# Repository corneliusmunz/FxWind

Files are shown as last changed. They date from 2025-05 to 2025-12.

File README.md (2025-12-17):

# FxWind

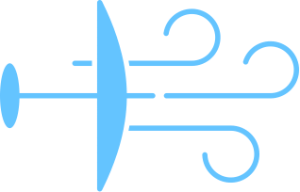
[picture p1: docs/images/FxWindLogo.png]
FxWind Logo


FxWind is a wind measurement tool for FAI Aeromodeling contests. In the FAI rules for 
different contest classes like F3B, F3J, F3K, etc. there are defined rules under which wind
conditions a contest can take place and under which conditions a contest has to be 
interrupted. FxWind will help you to comply with these competition rules.

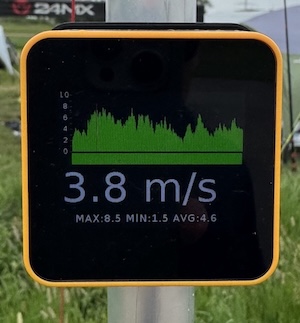
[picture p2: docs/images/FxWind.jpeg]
FxWind Display


All HW and SW Parts are published as open source and could be used to build your own measurement
tool. 

Feel free to open an issue or participate in the development by opening a pull request.

# Features

- [x] Battery powered. Last one complete competition day of at least 12 hours
- [x] Recharchable by USB-C in 2-3 hours
- [x] Additional Backup Power by USB-C
- [x] Magnetic connection between sensor and display, no wiring
- [x] 3D Printed parts for Microcontroller and accessories
- [x] Simple Alloy tube as base rig
- [x] Waterproof
- [x] Logging of Windspeed and Datetime on SD-Card for auditabilty, traceabiliy and possible complaints
- [x] 1s Sampling rate 
- [x] Wifi or Accesspoint connection to display the windspeed conditions on a webpage
- [x] Time synchronisation with NTP server and local backup of date and time with a Real Time Clock (RTC) 
- [x] Touch display with current windspeed and the needed ranges
- [x] Visualisation of regions in the time plot where the wind thresholds has exceeded
- [x] Accustic alarm if the condition are met to interrupt a contest

# How to use

You can find the operation manual on the following link
[Operation Manual](docs/OperationManual.md)

# Setup

## Mechanical setup

The windspeed sensor and the controller with display are mounted on a alloy tube which has the specified height of 2m above the ground. The original controller case of the M5Tough device is replaced by a 3D printed part which contains the rechargeable battery, the magnetic connector, the USB-C port and the magnetic Pogo Pin connector for the electric connection to the wind sensor. The controller and USB-C Port is sealed with an O-ring to ensure the waterproof design. The alloy tube is splitted into two parts for better transportability and could be sticked together with a tube connector. 

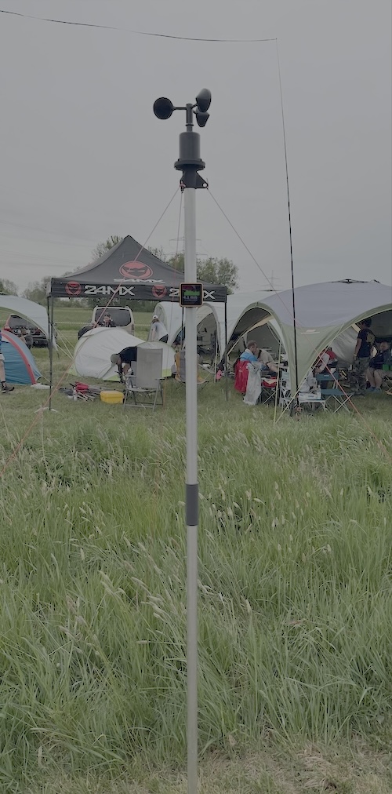
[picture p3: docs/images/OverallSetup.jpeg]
Overall setup

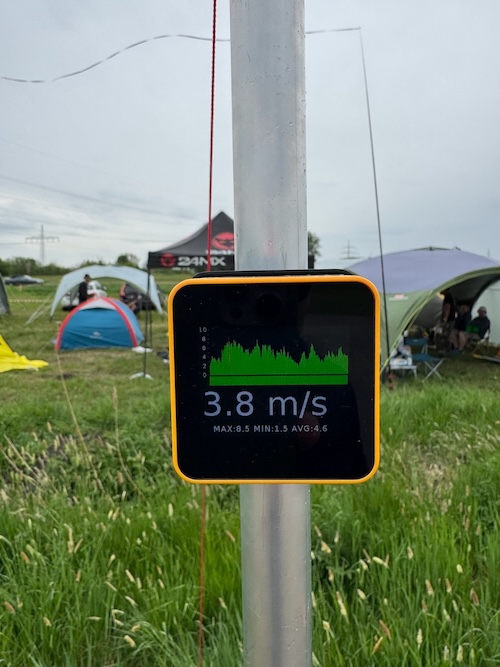
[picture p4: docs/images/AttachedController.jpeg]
Attached controller

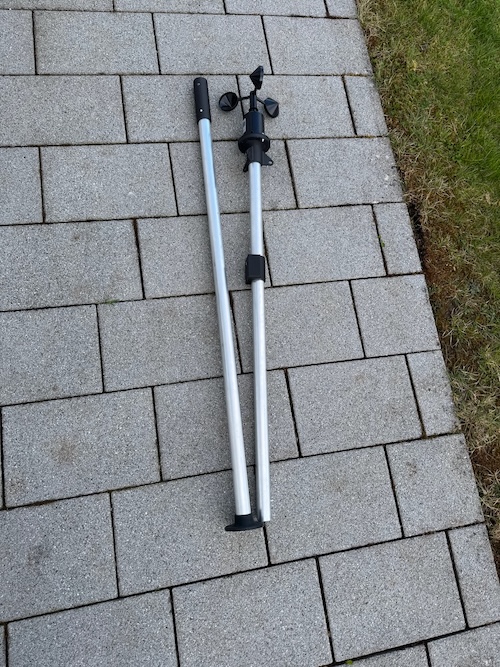
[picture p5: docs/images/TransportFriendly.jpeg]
Transport setup

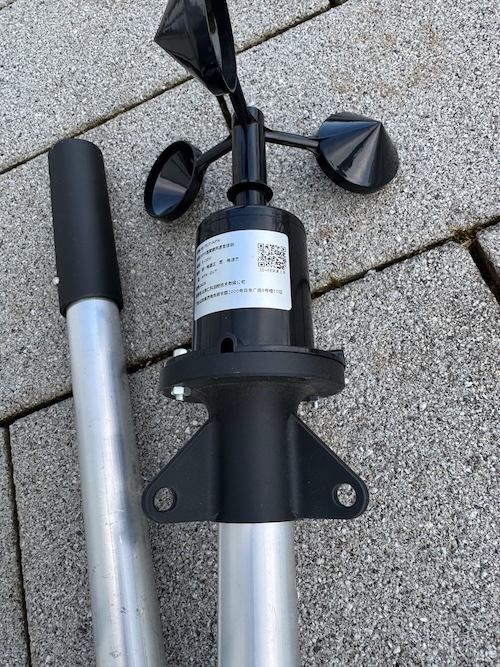
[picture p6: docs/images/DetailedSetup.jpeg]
Detailed setup

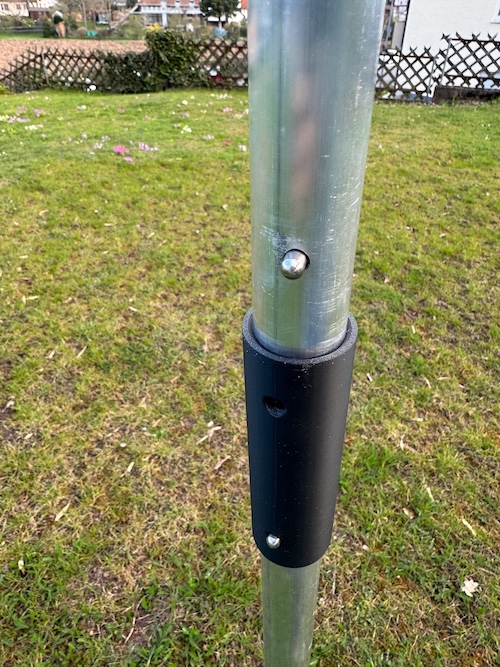
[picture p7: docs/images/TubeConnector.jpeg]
Tube connector


### CAD, STL Files 

## Electronic setup

### Wiring

## BOM

| Part | Quantity | Description | Link |
| --- | --- | --- | --- |
| M5Tough | 1 | Microcontroller with Touchscreen | https://docs.m5stack.com/en/core/tough |
| 1S 2000mAh Lipo | 1 | | https://www.amazon.de/dp/B08TQSC5G9 |
| Magnet | 1 | Magnet for connection between Controller and Base rig | https://www.amazon.de/dp/B0BKWQX36P |
| Windspeed Sensor | 1 | Windspeed sensor with impuls output and connection wiring | https://www.amazon.de/dp/B0C2F5MGKZ |
| Magnetic 3pin Pogo connector | 1 | Connection between Controller case and Base rig | https://www.amazon.de/dp/B0B1771YT4 |
| USB-C Port | 1 | USB-C Port for SW upload and as input for battery charge | https://www.amazon.de/dp/B0CZHDMFLZ |
| Ruthex M3S Brass Threads | 6 | M3 Short Brass inserts for meltin into the 3D Printed parts | https://www.amazon.de/dp/B09ZHSGHXD |
| M3x10 Flathead screw | 4 | Threads for clamp | |
| M3x6 countersunk screw | 2 | Threads for securing the magnet and the metal plate | |
| Alloy tube 30mm diameter | 2m | Base rig, 2x 1m length | |
| Base socket for Alloy tube | 1 | 3D printed part | [Base socket](construction/BottomStand.stl) |
| Windsensor socket | 1 | 3D printed part | [Windsensor socket](construction/TopStand.stl) |
| Controller case | 1 | 3D printed part | [Controller case](construction/FxWind_Case.stl) |
| Base plate for controller case | 1 | 3D printed part | [Base plate](construction/FxWind_ClampCase.stl) |
| Clamp | 1 | 3D printed part | [Clamp](construction/FxWind_Clamp.stl) |
| Tube connector | 1 | 3D printed part | [Tube connector](construction/FxWind_Connector.stl) |

## Assembly

You can find the assembly instructions on the following link
[Assembly Instructions](docs/assembly.md)

## Software

The software is based on the Arduino framework and is build, using the [PlatformIO](https://platformio.org)  develompent environment. You have two options to get the Software on the controller. You can build the Software by your own or you can use the provided binaries in the [Release](https://github.com/corneliusmunz/FxWind/releases) section and use an online flash tool. Both options are described in the next sections.

### Build

You can build the software by your own in opening the project in [PlatformIO](https://platformio.org) and choose the option ```Upload```. After the build process, the binaries will be flashed on the connected device. In a second step, you have to use the option ```Build Filesystem Image```. This step will generate a bin file which contains the html and image files which are needed for the web interface. In a last step, you have to use the option ```Upload Filesystem Image```. This will flash the filesystem image on your controller. 

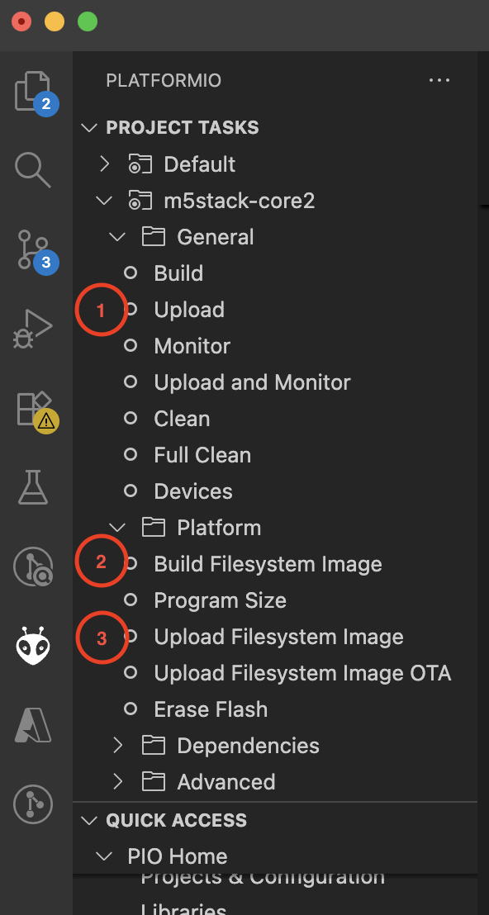
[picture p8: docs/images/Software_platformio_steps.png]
PlatformIO Build steps


### Flash without build

If you want to use the precompiled binaries out of the [Release section](https://github.com/corneliusmunz/FxWind/releases), you can open the following flash tool: https://espressif.github.io/esptool-js/ It is important, that you use the tool in a Chrome based browser. 

After opening the webpage, you have to change the baudrate to the value ```460800``` and press the ```Connect``` Button. 

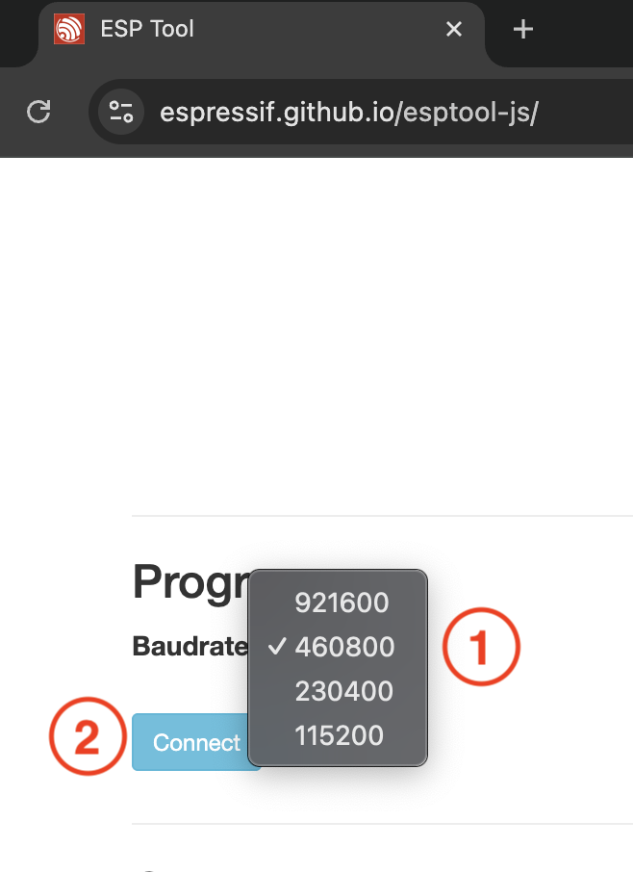
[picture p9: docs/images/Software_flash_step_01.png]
Flash step 1


The next step is to erase the flash on the controller. After doing this, enter the Flash Address ```0x0```and select the ```firmware-merged.bin```file out of the release assets. Then press the ```Program``` button and wait until the flash process is finished. 

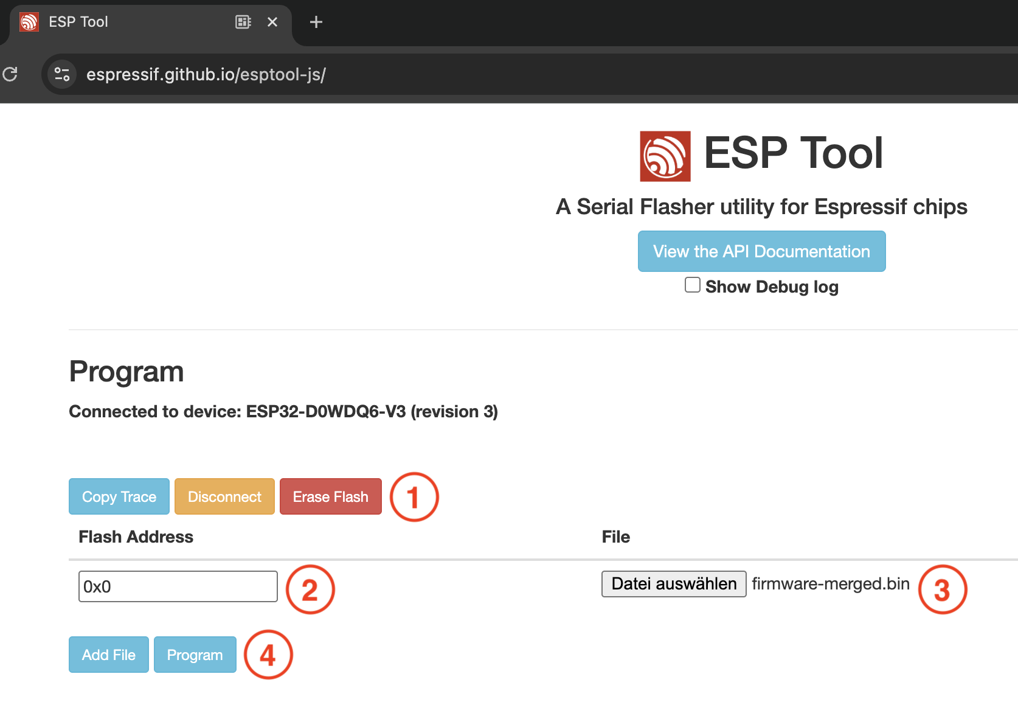
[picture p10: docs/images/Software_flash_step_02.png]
Flash step 2


In the final step, the filesystem has to be flashed on the controller. For this task you have to enter the Flash Address ```0x00c90000``` and select the ```littlefs.bin``` file out of the release assets. Then press the ```Program``` button. Now you are done and the controller is ready to go.

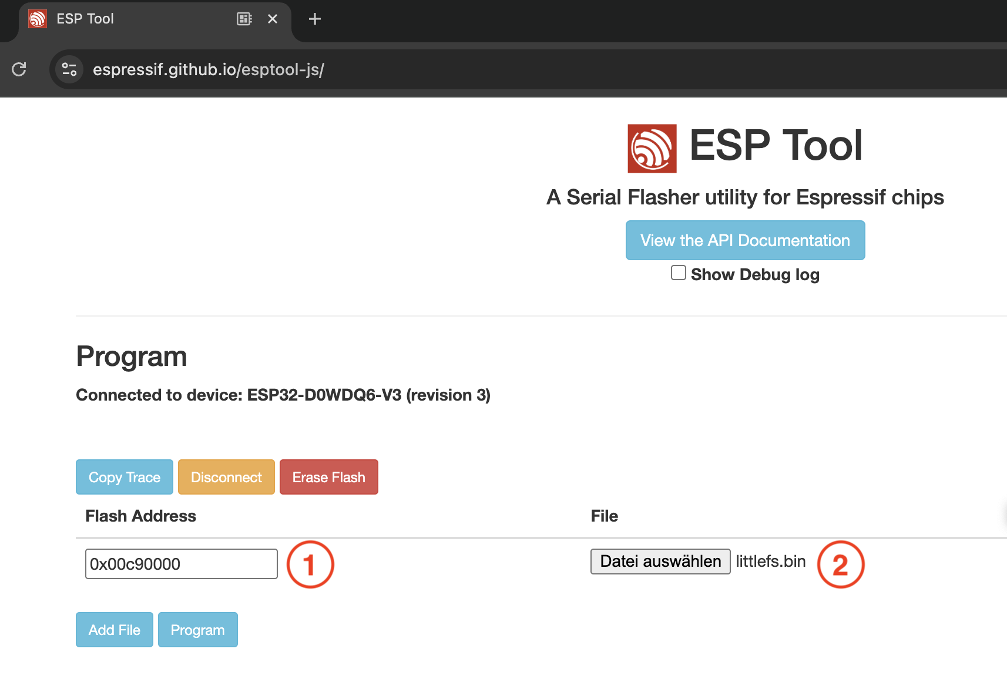
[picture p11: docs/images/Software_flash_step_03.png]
Flash step 3


# Ideas and open issues

- [ ] BLE connection 

# Appendix

## FAI rule links

FAI Sporting code rc modeling soaring 
https://www.fai.org/sites/default/files/sc4_vol_f3_soaring_25.pdf

### Overview of conditions for different FAI competition categories

| Category | Lower Windspeed threshold [m/s] | Upper Windspeed threshold [m/s] | Window duration [s] | Number of windows exceeded |
| --- | --- | --- | --- | --- |
| **Gerneral** | 0 | 12 | 60 | 1 |
| **F3K** | 0 | 8 | 20 | 3 |
| **F3B** | 0 | 12 | 20 | 3 |
| **F3G** | 0 | 12 | 20 | 3 |
| **F3J** | 0 | 12 | 20 | 3 |
| **F3L** | 0 | 8 | 60 | 1 |
| **F3F** | 3 | 25 | 20 | 1 |
| **F1x** | 0 | 9 | 20 | 1 |
| **F2x** | 0 | 9 | 30 | 1 |
| **F3C/F3N**  | 0 | 8 | 20 | 1 |

### Extracts

Extracts of the sporting codes of different FAI competition categories

#### CIAM General rules

> C.17.2 Interruption
> a) The contest should be interrupted or the start delayed by the contest director in the following
> circumstances and in other exceptional circumstances decided by the contest director:
> i) Unless specified otherwise in the rules for a category or a particular class, the wind is
> continuously stronger than **12 m/s** measured **at two (2) metres** above the ground at the starting
> line (flight line), **for at least one minute**

#### Soaring F3B

> F3B.1.11. Weather Conditions / Interruptions
> a) The maximum wind speed for F3B contests is twelve (12) m/sec. The > contest has to be interrupted
> or the start delayed by the contest director if the wind speed exceeds > twelve (12) m/sec measured three (3)
> times for at least twenty (20) seconds in a time interval of five (5) > minutes two (2) metres above the ground
> at the start and landing area.

#### Soaring F3F

> F3F.1.17. Weather Conditions and interruptions
> A round in progress must be interrupted if:-
> The wind speed is below three (3) m/sec or more than twenty-five (25) m/> sec for at least twenty (20)
> a) seconds.
> b) The direction of the wind deviates more than 45º from a line > perpendicular to the main direction of
> the speed course for at least twenty (20) seconds.
> The wind speed and wind direction are measured with the equipment of the > organiser at a representative
> position and height chosen from the experience of the organiser.

#### Soaring F3G

> F3G.1.12. Weather Conditions/Interruptions
> a) The maximum wind speed for F3G contests is twelve (12) m/sec. The > contest has to be interrupted
> or the start delayed by the contest director if the wind speed exceeds > twelve (12) m/sec measured three (3)
> times for at least twenty (20) seconds in a time interval of five (5) > minutes two (2) metres above the ground
> at the start and landing area.

#### Soaring F3J

> F3J.12. WEATHER CONDITIONS AND INTERRUPTIONS
> The maximum wind speed for F3J contests is twelve (12) m/sec two (2) m > above the ground at the centre of
> the launch corridor. The start of the contest must be delayed or the > contest has to be interrupted by the
> contest director if the wind speed exceeds twelve (12) m/sec measured > three (3) times for at least twenty
> (20) sec in a time interval of five (5) minutes at the start and landing > area.

#### Soaring F3K

> F3K.5. WEATHER CONDITIONS / INTERRUPTIONS
> The maximum wind speed for F3K contests is eight (8) m/sec. The start of > the contest must be delayed or
> the contest has to be interrupted by the contest director if the wind > speed exceeds eight (8) m/sec measured
> three (3) times for at least twenty (20) sec in a time interval of five > (5) minutes at two (2) metres above the
> ground at the start and landing field. In the case of rain, the contest > director can interrupt the contest. When
> the rain stops, the contest starts again with the group that was flying, > which receives a re-flight.

#### Soaring F3L

> F3L.6 Interruptions
> a) The Contest Director has the right to interrupt the competition and > relocate the starting line
> when the wind direction deviates too much or becomes a tailwind.
> b) The competition shall be interrupted by the Contest Director if the > wind is continuously
> stronger than eight (8) m/s measured at two (2) metres above the ground > at the starting line (flight
> line), for at least one minute.

#### Helicopter

> INTERRUPTION OF A COMPETITION
> If the wind component perpendicular to the flight line exceeds 8ms/s for > a minimum of 20 seconds
> during a flight, the competition must be interrupted. The flight will be > repeated and the competition
> continued as soon as the wind subsides below the criterion. If the wind > does not subside before the
> round is completed, the entire round will be dropped. The determination > will be made by the organiser
> with concurrence of the FAI Jury.

#### Free flight

> F1.5 INTERRUPTION OF A CONTEST
> F1.5.1 Wind speed
> The interruption of contests is defined in CIAM General Rules C.17.2. > For Free Flight contests the
> contest should be interrupted when the wind measured at 2 metres above > the ground at the starting
> line is stronger than 9 m/s for at least 20 seconds.

#### Control line

> 4.0.1 INTERRUPTION OF THE CONTEST
> Wind stronger than 9 m/s for at least 30 seconds (instead of 12 m/s for > at least one minute in
> CIAM General Rules).

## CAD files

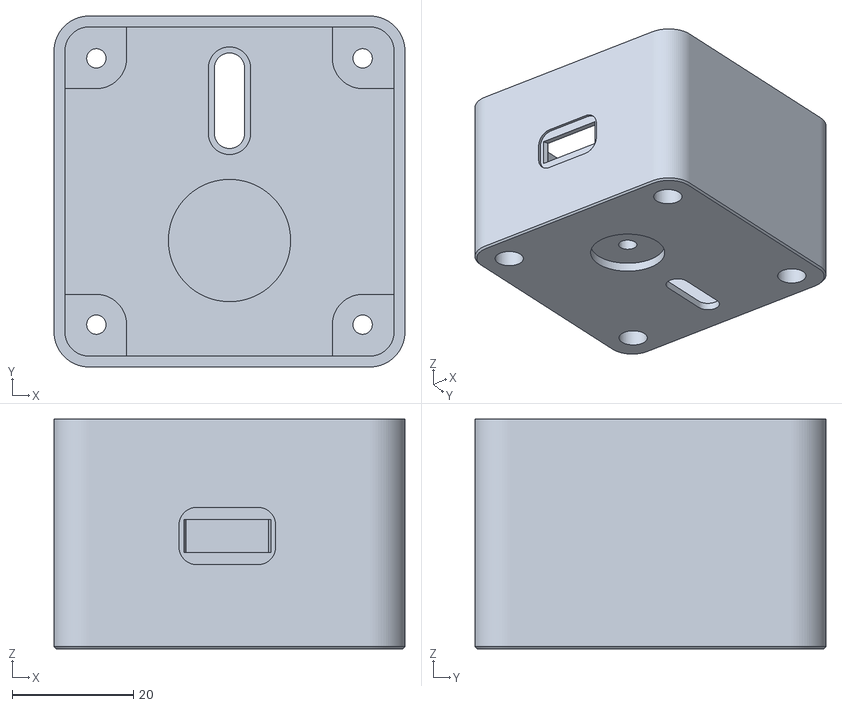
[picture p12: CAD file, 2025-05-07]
construction/FxWind_Case.stl
58.0 x 58.0 x 38.0

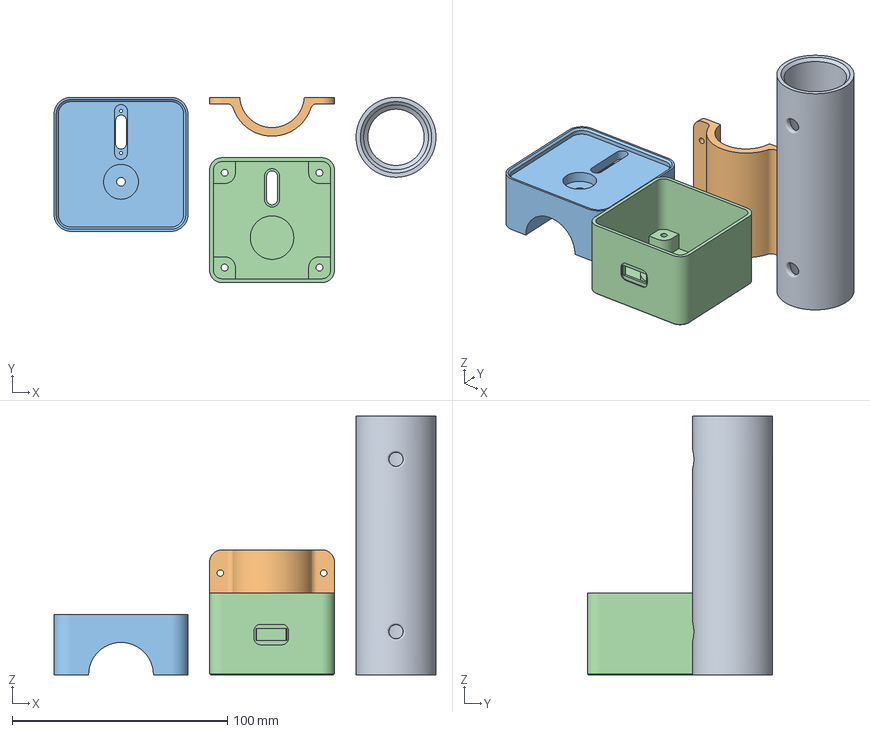
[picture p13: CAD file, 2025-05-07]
construction/FxWind.3mf
177.3 x 86.0 x 120.0 mm
FxWind_Connector.stl
FxWind_Clamp.stl
FxWind_ClampCase.stl
FxWind_Case.stl

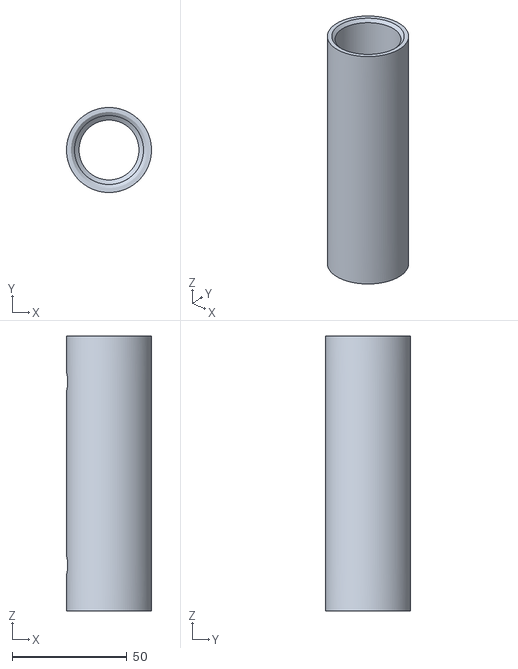
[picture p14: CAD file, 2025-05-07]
construction/FxWind_Connector.stl
37.1 x 37.1 x 120.0

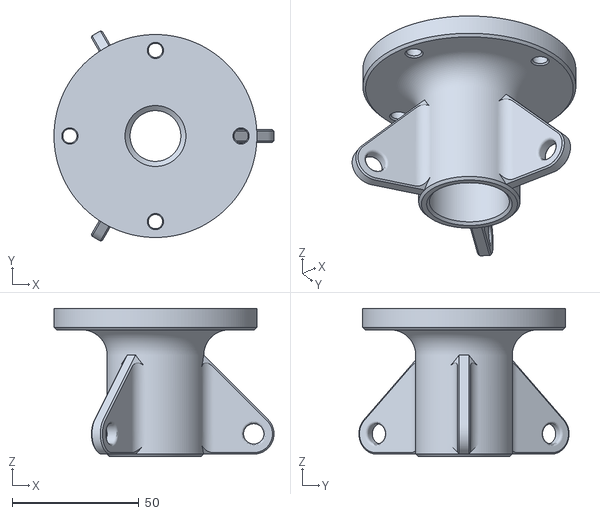
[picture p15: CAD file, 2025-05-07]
construction/TopStand.stl
86.7 x 82.8 x 58.5

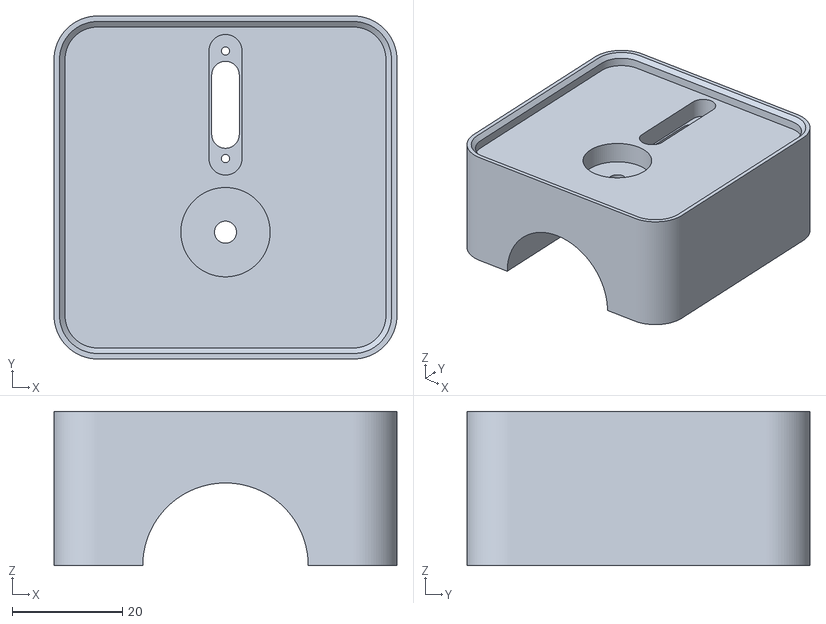
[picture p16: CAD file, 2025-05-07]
construction/FxWind_ClampCase.stl
62.2 x 62.2 x 28.0

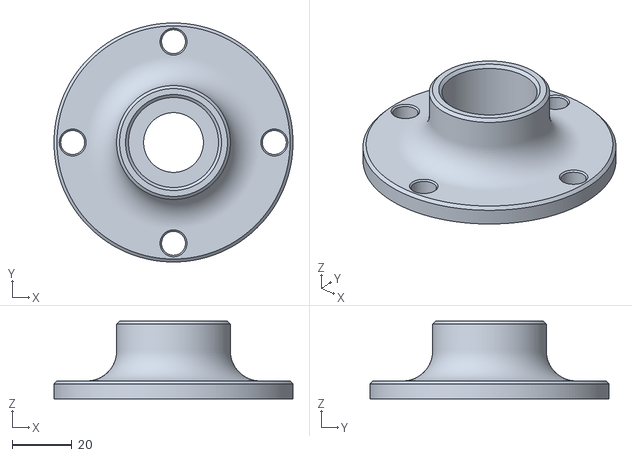
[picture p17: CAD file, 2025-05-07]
construction/BottomStand.stl
80.0 x 80.0 x 26.0

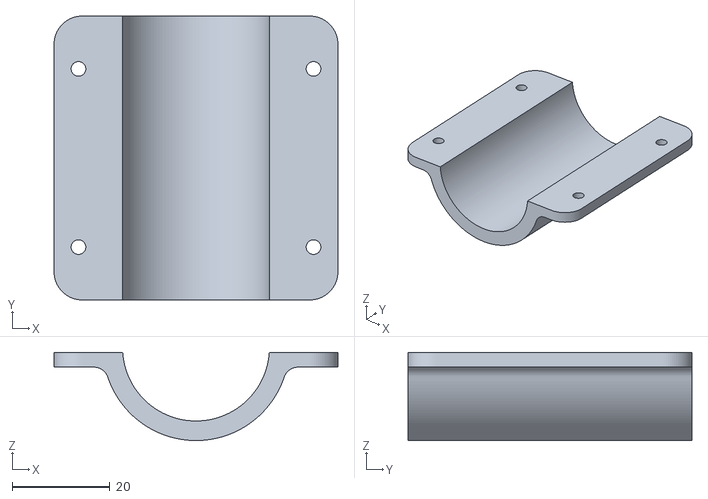
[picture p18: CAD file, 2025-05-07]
construction/FxWind_Clamp.stl
58.0 x 58.0 x 18.0

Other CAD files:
construction/FxWind.f3d

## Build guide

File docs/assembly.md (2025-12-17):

# Assembly

After you have ordered and printed all the materials on the BOM, you can start the assembly of the measurement device. 

## Brass threads

To mount the magnet we have to melt 2 Ruthex M3S Brass Threads into the controller body and the clamp body. Additionally we have to melt 4 Ruthex M3 Brass Threads into the clamp body

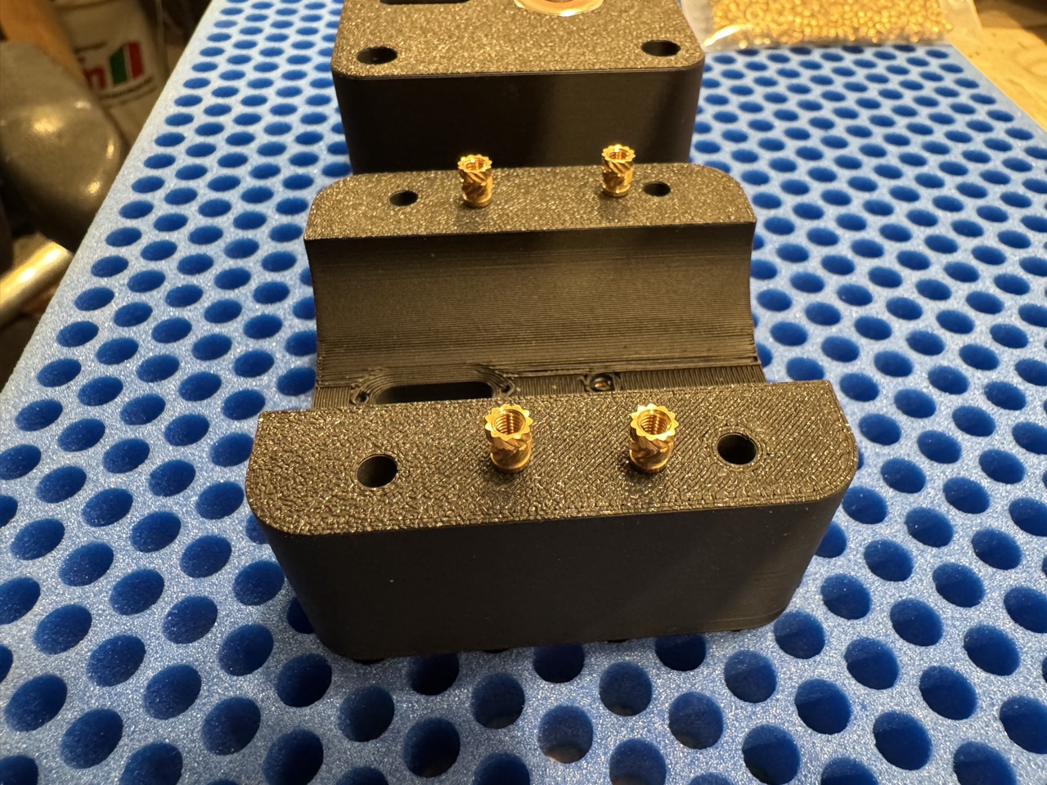
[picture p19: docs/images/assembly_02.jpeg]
Brass threads


## Magnet
The magnet and spacer is mounted with two M3x6 countersunk screws. The magnet is part of the clamp body and the spacer is part of the controller body.

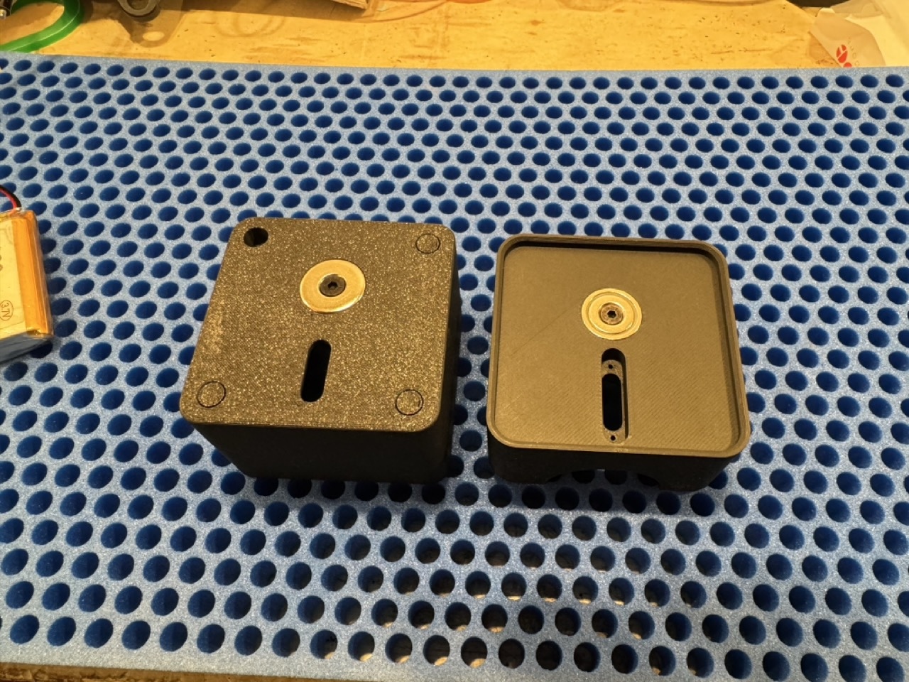
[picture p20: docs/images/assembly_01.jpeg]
Magnet mount


## Battery 
The Battery out of the BOM is unfortunately delivered with a connector with the wrong polarity. So pay **ATTENTION** to solder the connector with the opposite polariy. Plus and Minus poles are marked on the controller board. Please check the polarity before connect the battery to the controller board. The battery connector should look as follows
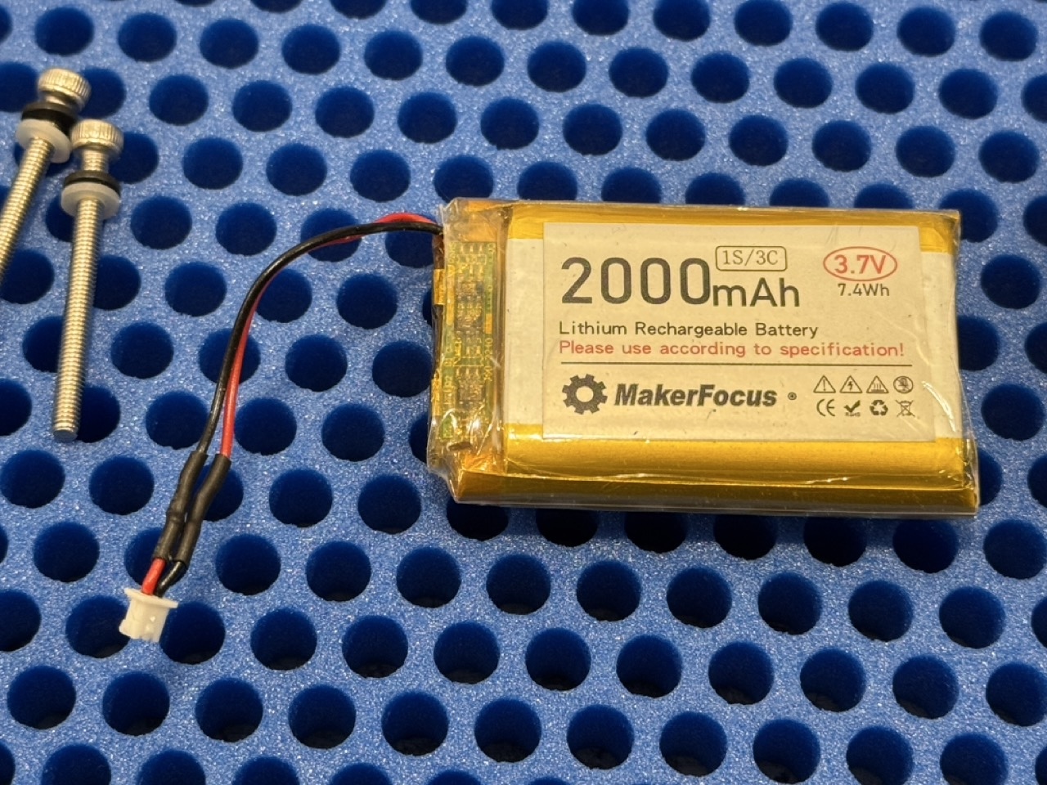
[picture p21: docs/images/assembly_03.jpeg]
Battery connector


## USB cable
The USB cable which is used for charging the battery and flashing the software on the controller should be soldered together with the following mapping. 

| USB female plug | M1250V-04P connector | Pin |
| --- | --- | --- |
| black | black | GND |
| red | red | +5V |
| white | yellow | D-  |
| blue | green | D+  |

The soldered cable should look as follows
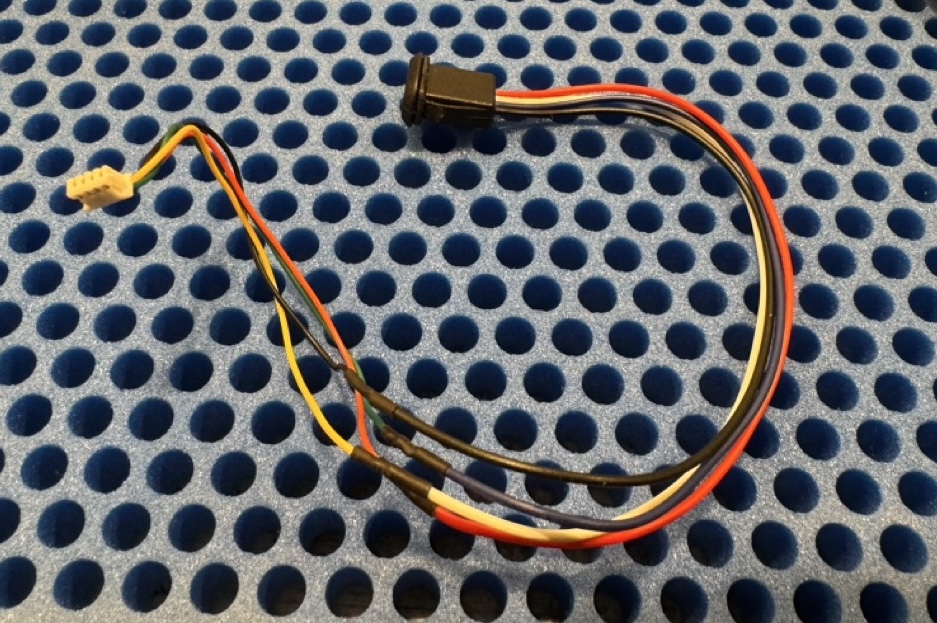
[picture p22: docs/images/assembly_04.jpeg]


After soldering the cable can be inserted into the controller case. Use an O-ring (seal ring) on the USB female plug before inserting the plug into the case. You have to apply a decent amount of pressure to "click" the plug into the case. 

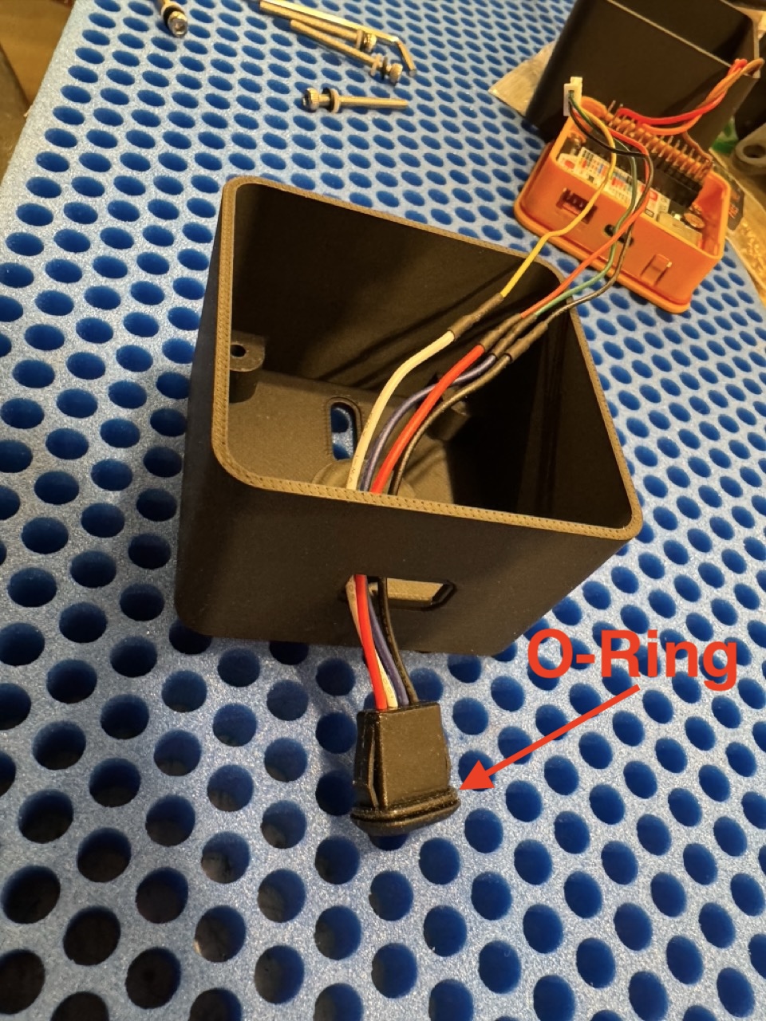
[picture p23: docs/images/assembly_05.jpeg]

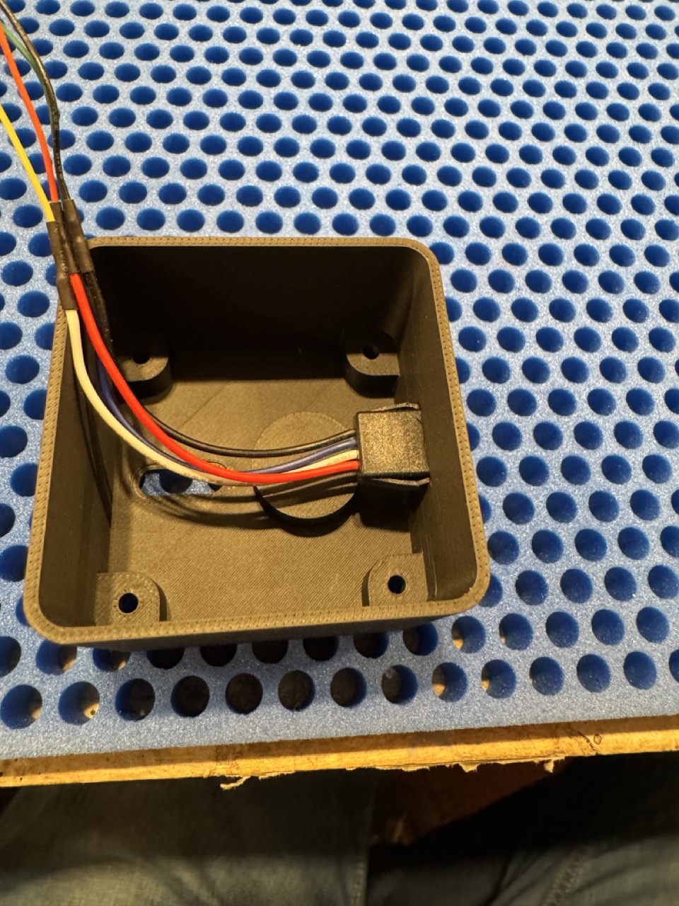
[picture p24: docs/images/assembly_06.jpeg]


## POGO Pin connectors
The connection between controller case and the windspeed sensor itself is done with a 3pin magnetic POGO connector. The connector is soldered and glued into the controller case.

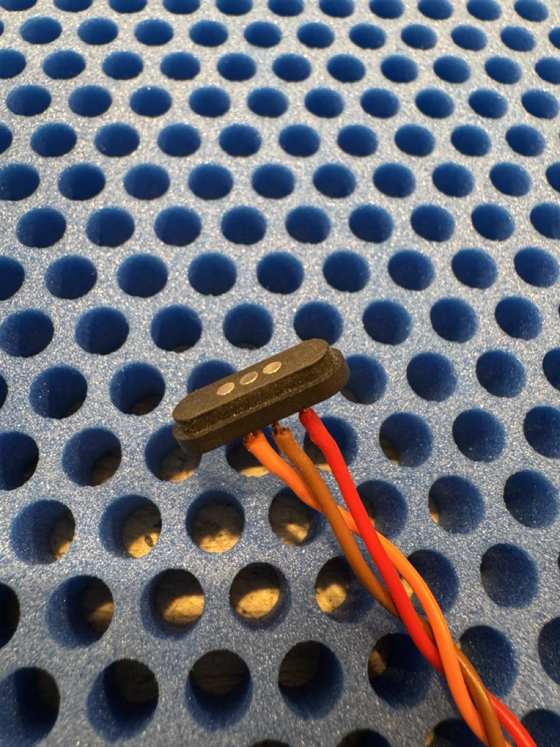
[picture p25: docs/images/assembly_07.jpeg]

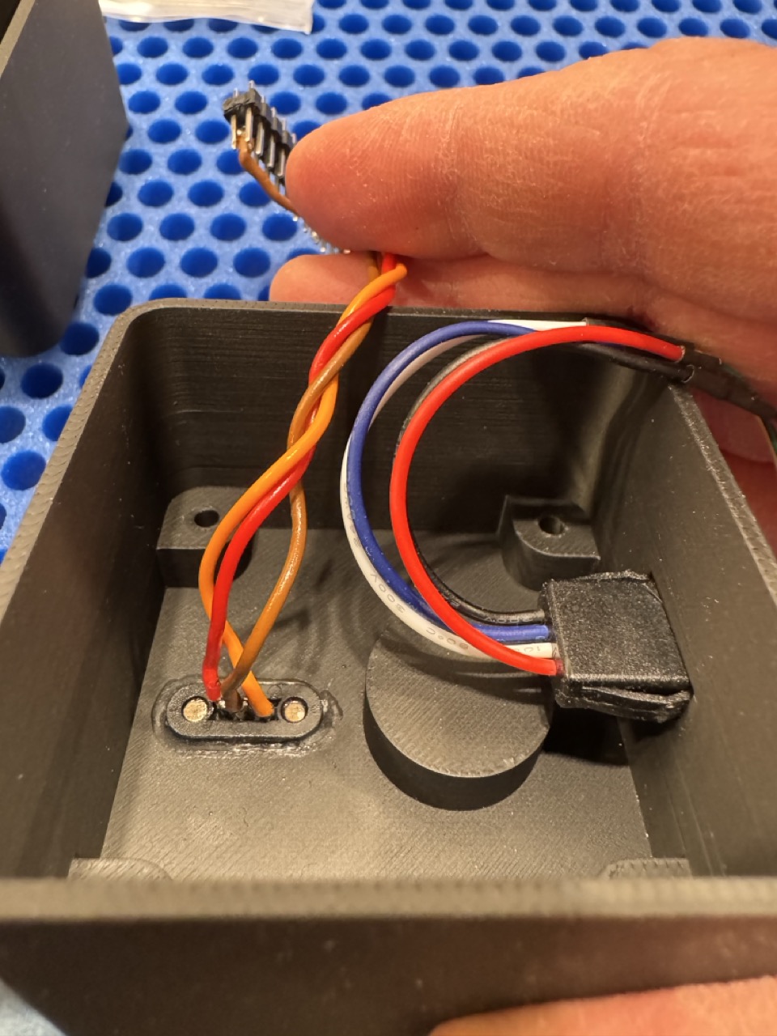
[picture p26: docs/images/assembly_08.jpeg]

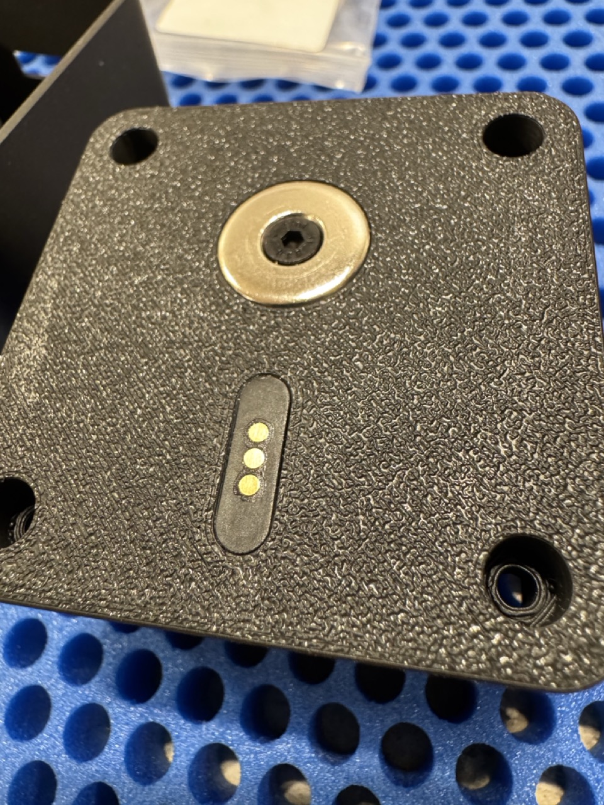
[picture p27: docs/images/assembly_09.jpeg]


## Windspeed connector
The Windspeed sensor has an positive and negative impuls output and needs a power supply. The following mapping is used

| Windspeed sensor | Signal |
| --- | --- |
| black | GND |
| brown | +5V |
| blue | Positive impuls signal |
| yellow | Negative impuls signal (not needed) |

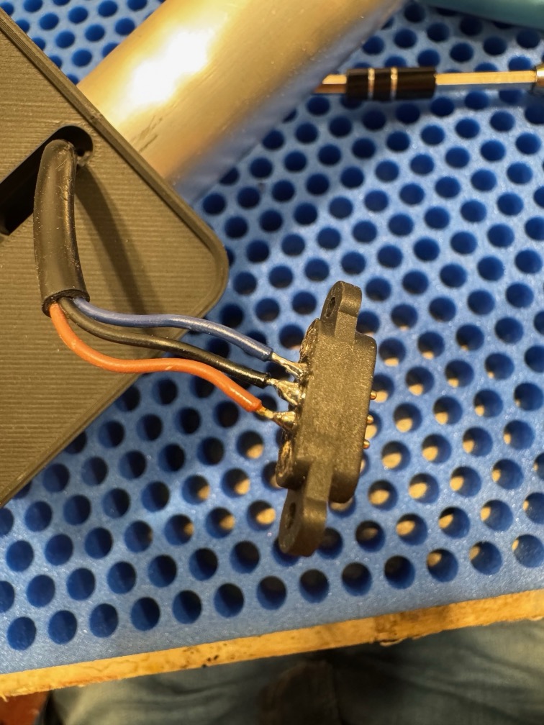
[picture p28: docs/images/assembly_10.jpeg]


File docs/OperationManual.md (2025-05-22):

# FxWind Operation Manual
FxWind Logo

## Power on/off
To power on the device, just tap the screen. A short startup sound is played. To power off the device you have to press and hold the touchscreen for at least 3 seconds. If the three seconds are reached, a short shutoff sound is played and you can release your touch.

## Charging

To charge the device, you have to use a USB-A to USB-C cable. Unfortuntately a USB-C to USB-C cable does not work. Charging will start immedieately after you have plugged in the USB cable. It will stop automatically if the Battery is fully charged. If the device is switched on, you can see the charging current and the battery level in the status screen. In the web view, you can configure the maximum charging current. The default setting is 800mA max charge current. This will give you a full battery after 2-3 hours.

## Operation Modes

After the startup of the device you can select different operation modes which will be explained in the next sections.

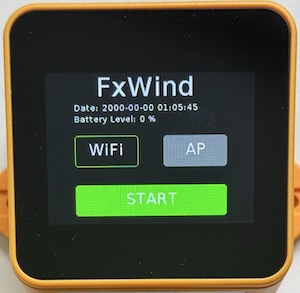
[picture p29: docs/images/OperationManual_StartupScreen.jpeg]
Startup Screen


### Standalone Mode

In the standalone mode the Real time clock of the device is used to store data on the SD card. This mode is always available and has no need of a local Wifi connection. This is the least power consuming mode but will not display data in a browser view. Only the device integrated display will be used.

### Wifi Mode

In Wifi Mode, the device will try to connect to a local available Wifi  network. The webpage with the measurment data will be available on a local IP address of that WiFi network. 

To configure the Wifi Mode, the display will show you the hint to open the  Accesspoint "**fxwind Accesspoint**". 

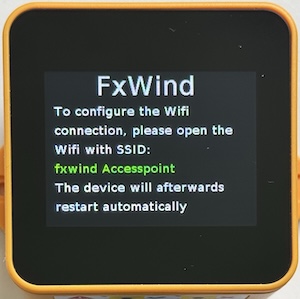
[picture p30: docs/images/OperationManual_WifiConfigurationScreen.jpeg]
Wifi Configuration Screen


The accesspoint will automatically open a webpage where you can choose your Wifi network to which you want to connect and you can enter the password for that Wifi network. After storing the settings, the device will automatically try to connect to the configured Wifi network and will store the settings for the next startup of the device. Once configured, you have not to enter the credentials again.

After a valid configuration, you can acccess the webpage of the device in the lokal Wifi network with entering the following address in your browser: [fxwind.local](fxwind.local)

Alternatively, the device will show up a QR code with the address and you can scan that code with your mobile phone. Just swipe through on the display several times till a QR code is presented.

### Accesspoint (AP) Mode

The accesspoint mode will also serve a webpage with the display of the current measurement data. But it will not need a connection to a local Wifi network. Instead it provides an accesspoint where a Wifi device could be connected to. 

## Display usage

The display is a touch display which supports the following gestures

### Swipe (left/right)

After the Startup screen, you are in the main screen mode of the device and here you can use left and right swipe gestures to switch between different screens.

### Single press
Will switch ON the device

### Long press > 3s
Will shut OFF the device

### Double tap
Will switch off the Alarm sound 

## Different Displays

### Combined/Default Screen
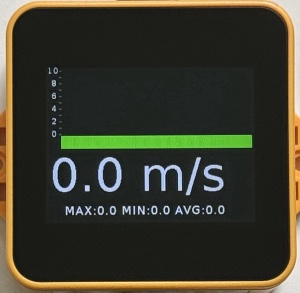
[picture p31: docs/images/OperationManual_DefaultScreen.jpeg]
Default Screen


### Status Screen

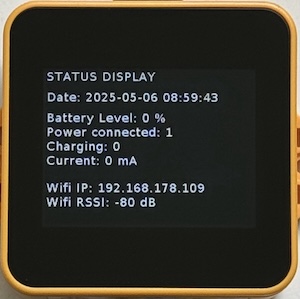
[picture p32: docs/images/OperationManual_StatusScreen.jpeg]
Status Screen


### QR Code Screen

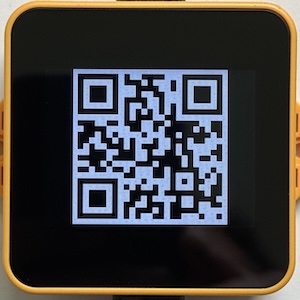
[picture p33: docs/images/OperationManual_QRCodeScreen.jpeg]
QR Code Screen


## Alerts

If the FAI condition to interrupt th competition is reached, a sound alarm is activated which has to be confirmed manually by double tap on the display.

## Webpage

If you have enabled Wifi or AP Mode, you are able to see the visualization of the measurement values online. After you have connected your device to the Wifi or to the accesspoint, you can reach the webpage with the http://fxwind.local link.

The webpage ist structured in the following tabs:

### Live Data
In the *Live Data* tab, you can have an overview of the current wind speed, the wind speed in the past 300 seconds and the status:

| Color | Status |
| --- | --- |
| **GREEN**  | Windspeed has not reached threshold for longer than 20 seconds in the last 300 seconds |
| **YELLOW** | Windspeed has at least once reached the threshold for longer than 20 seconds in the last 300 seconds |
| **RED** | Windspeed has reached at least 3 times the threshold for longer than 20 seconds in the last 300 seconds --> FAI rule for interruption of competion is reached |

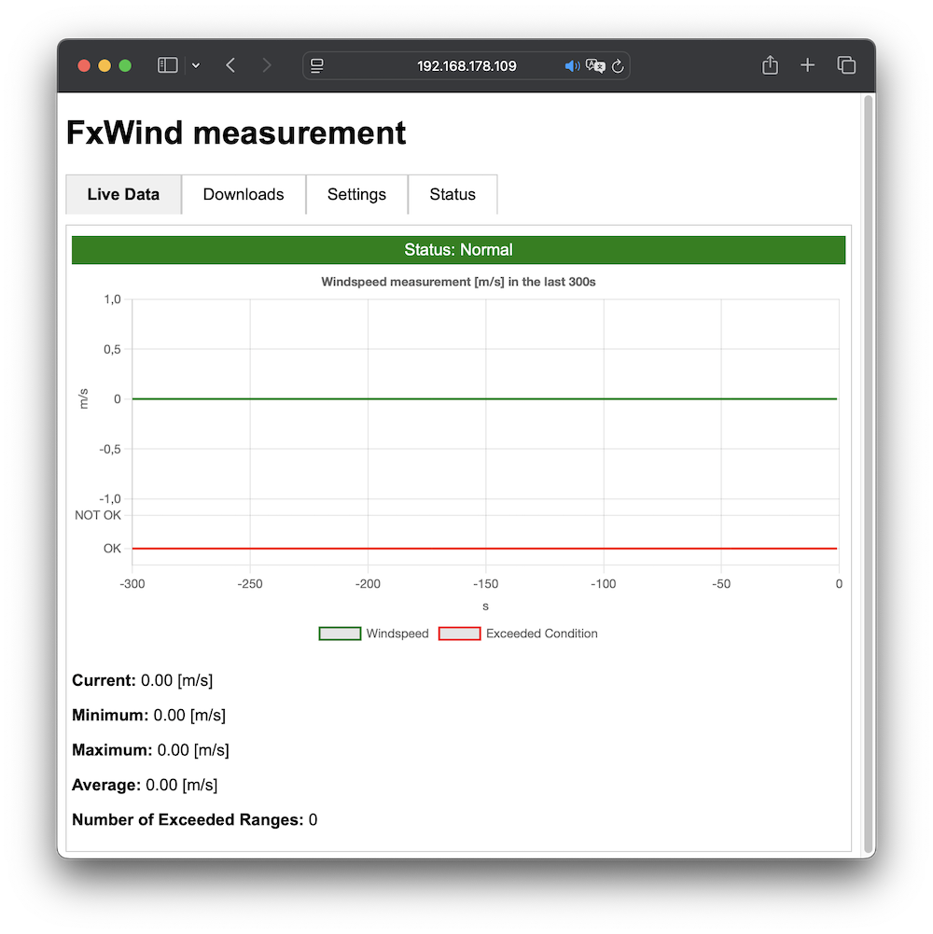
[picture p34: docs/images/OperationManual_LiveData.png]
Live Data


### Downloads

In the *Download* tab you can see the list of all available *.csv files on the SD-Card. One file is generated per day. If you press the link of the file, a download will start and you can open the file on your local computer.

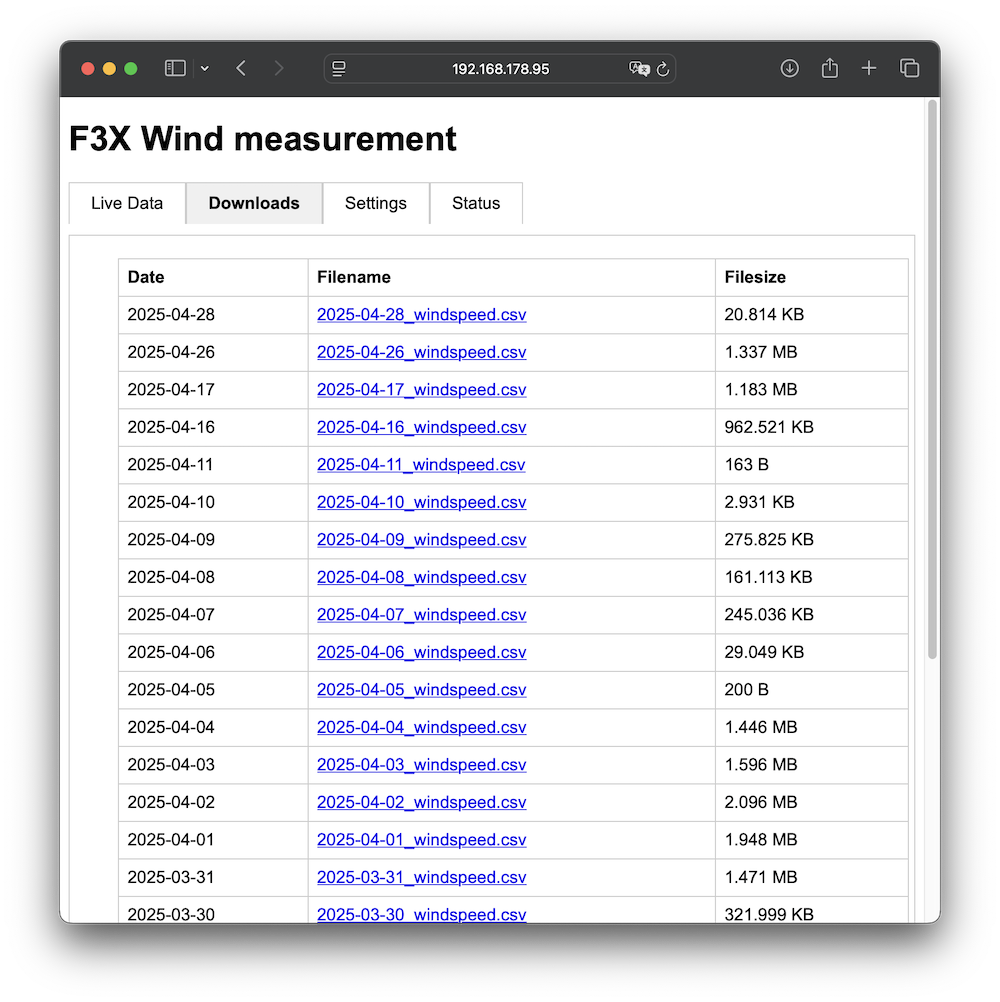
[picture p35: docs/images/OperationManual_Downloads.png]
Downloads


### Settings

In the *Settings* tab you can change the following configuration parameters

| Setting | Description |
| --- | --- |
| Lower Threshold [m/s] | Lower FAI wind threshold 0..5 m/s |
| Upper Threshold [m/s] | Upper FAI wind threshold 2..25 m/s |
| Duration of Window [s] | Duration, how long the windspeed should be inside thresholds 10..120 s |
| Number of Windows | Number of windows which should be reached for contest abortion 1..10 |

| Volume [%]                  | Speaker volume 0..100%                                  |
| Maximum Charge current [mA] | Maximum charge current 100..1000 mA for 2000mAh battery |
| Display Brightness [%]      | Display background brightness level 0..100%             |

By pressing one of the FAI Category buttons, the default values for that category out of the FAI Rules are updated in the fields. You have to press Save to apply the settings.

To reset/erase the saved WiFi settings, you can press the lower button.

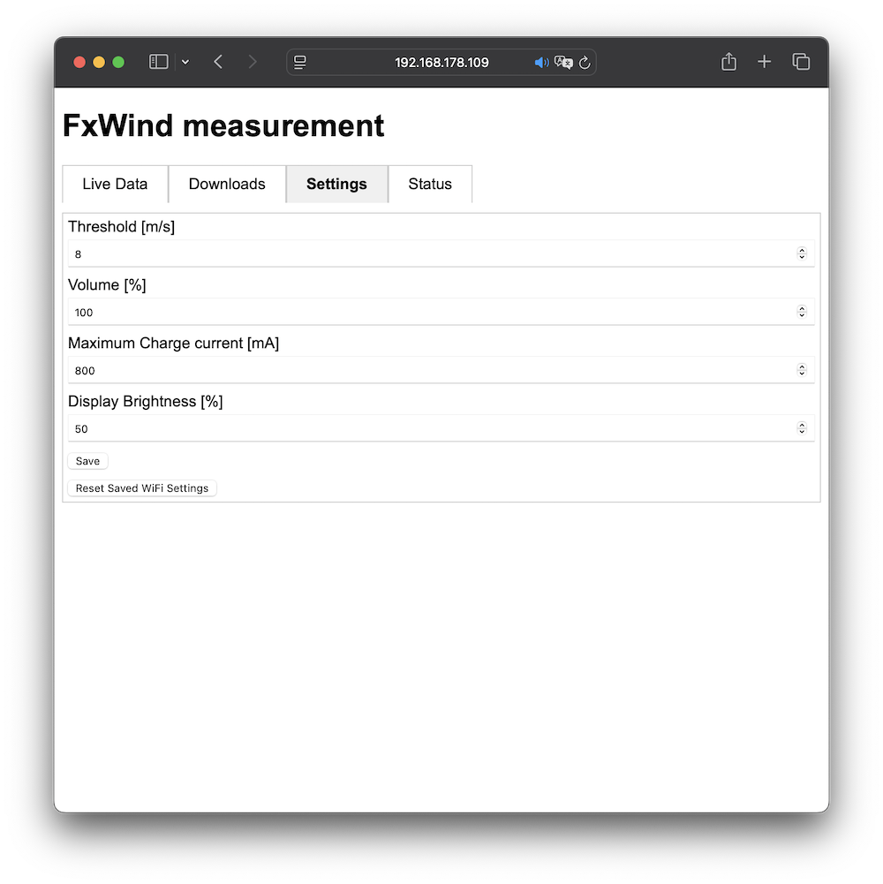
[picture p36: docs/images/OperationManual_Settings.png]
Settings


### Status

In the *Status* tab you can see the current status values of the device.

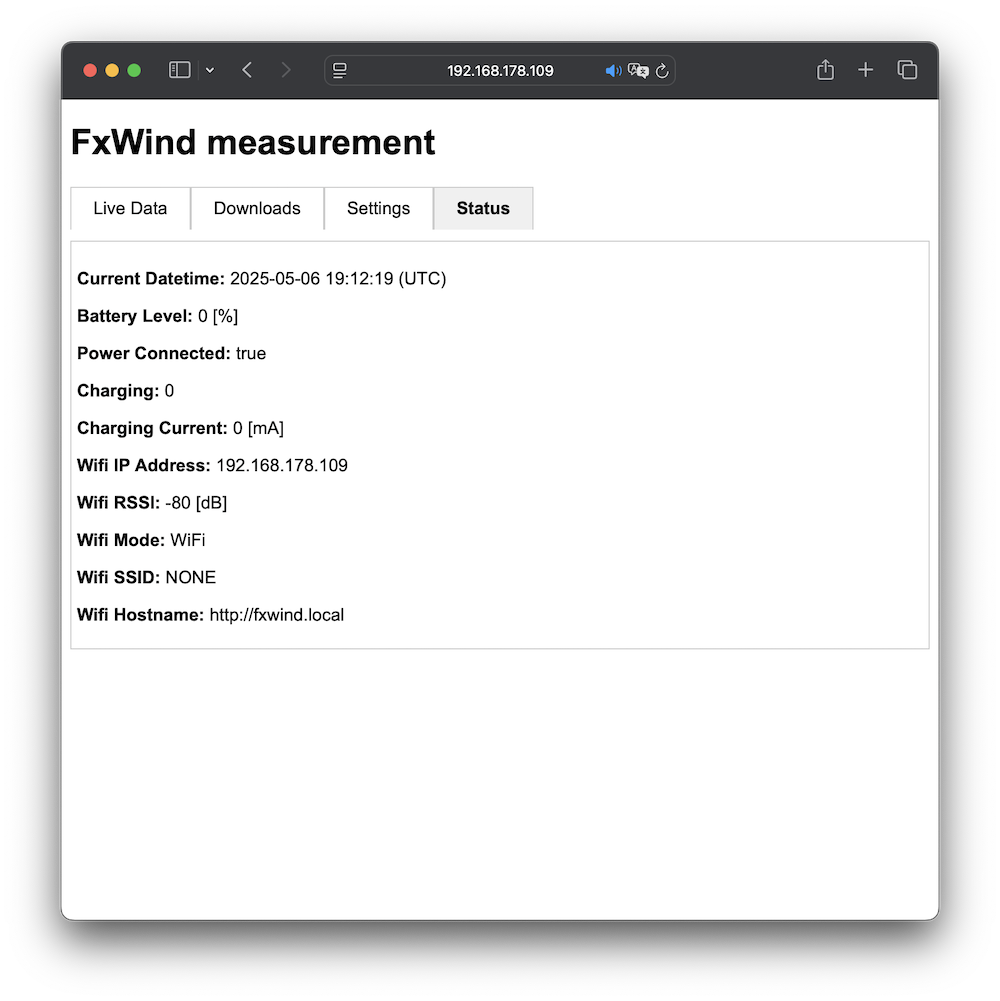
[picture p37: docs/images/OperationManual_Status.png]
Status


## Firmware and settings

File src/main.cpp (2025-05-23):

#include <SD.h>
#include <M5GFX.h>
#include <M5Unified.h>
#include <WiFiManager.h>
#include <TimeLib.h>
#include <ESPAsyncWebServer.h>
#include <ESPmDNS.h>
#include <ArduinoJson.h>
#include <LittleFS.h>
#include "WindSpeed.h"
#include "WindSpeedDisplay.h"
#include "StartupDisplay.h"
#include <Preferences.h>
#include "WifiConfigDisplay.h"
#include <ESPAsyncHTTPUpdateServer.h>

// constants
#define WINDSPEED_PIN 19
#define WINDSPEED_EVALUATION_RANGE 300
#define SAMPLE_RATE 1000            // ms
#define WINDSPEED_LOWER_THRESHOLD 0 // m/s
#define WINDSPEED_UPPER_THRESHOLD 8       // m/s
#define WINDSPEED_DURATION_RANGE 20 // samples
#define WINDSPEED_NUMBER_OF_WINDOWS 3
#define TIME_SYNC_INTERVAL 600
#define VOLUME 100            // %
#define DISPLAY_BRIGHTNESS 50 // %
#define CHARGE_CURRENT 800    // mA
#define PREFERENCE_NAMESPACE "fxwind"
#define MDNSNAME "fxwind"
#define AP_SSID "fxwind Accesspoint"

// structs, enums
struct Settings
{
  int Volume;
  int CalibrationFactor;
  int LowerWindspeedThreshold;
  int UpperWindspeedThreshold;
  int WindspeedEvaluationRange;
  int WindspeedDurationRange;
  int WindspeedNumberOfWindows;
  int DisplayBrightness;
  int MaximumChargeCurrent;
};

// global variables
Preferences preferences;
WiFiManager wifiManager;
M5GFX display;
Settings settings = {VOLUME, 1, WINDSPEED_LOWER_THRESHOLD, WINDSPEED_UPPER_THRESHOLD, WINDSPEED_EVALUATION_RANGE, WINDSPEED_DURATION_RANGE, WINDSPEED_NUMBER_OF_WINDOWS, DISPLAY_BRIGHTNESS, CHARGE_CURRENT};
WindSpeed windSpeed(WINDSPEED_PIN, settings.LowerWindspeedThreshold, settings.UpperWindspeedThreshold, settings.WindspeedDurationRange, settings.WindspeedEvaluationRange, settings.WindspeedNumberOfWindows, settings.CalibrationFactor);
WindSpeedDisplay windSpeedDisplay(settings.LowerWindspeedThreshold, settings.UpperWindspeedThreshold, settings.WindspeedEvaluationRange, settings.WindspeedDurationRange, &windSpeed);
StartupDisplay startupDisplay;
WifiConfigDisplay wifiConfigDisplay;

WiFiUDP Udp;
ESPAsyncHTTPUpdateServer updateServer;
AsyncWebServer server(80);
unsigned long lastMillis;
static const char *hostname = "f3xwind";
static const char ntpServerName[] = "de.pool.ntp.org";
unsigned int localPort = 8888;
const int timeZone = 0;
const int NTP_PACKET_SIZE = 48;
byte packetBuffer[NTP_PACKET_SIZE];
int menuX = 0;
bool isAlarmActive = false;
bool isStartupActive = true;
bool isAPModeActive = true;
bool isWifiOn = false;
int touchDuration = 0;
bool isSwitchoffSoundActive = false;

static constexpr const char *menu_x_items[4] = {"Combined", "Plot", "Number", "Stats"};

void saveSettings();

void interruptCallback(void)
{
  windSpeed.interruptCallback();
}

// send an NTP request to the time server at the given address
void sendNTPpacket(IPAddress &address)
{
  // set all bytes in the buffer to 0
  memset(packetBuffer, 0, NTP_PACKET_SIZE);
  // Initialize values needed to form NTP request
  // (see URL above for details on the packets)
  packetBuffer[0] = 0b11100011; // LI, Version, Mode
  packetBuffer[1] = 0;          // Stratum, or type of clock
  packetBuffer[2] = 6;          // Polling Interval
  packetBuffer[3] = 0xEC;       // Peer Clock Precision
  // 8 bytes of zero for Root Delay & Root Dispersion
  packetBuffer[12] = 49;
  packetBuffer[13] = 0x4E;
  packetBuffer[14] = 49;
  packetBuffer[15] = 52;
  // all NTP fields have been given values, now
  // you can send a packet requesting a timestamp:
  Udp.beginPacket(address, 123); // NTP requests are to port 123
  Udp.write(packetBuffer, NTP_PACKET_SIZE);
  Udp.endPacket();
}

time_t getRtcTime()
{
  // Get the current RTC datetime
  auto dateTime = M5.Rtc.getDateTime();

  // Populate the tm structure
  struct tm t;
  t.tm_year = dateTime.date.year - 1900; // tm_year is years since 1900
  t.tm_mon = dateTime.date.month - 1;    // tm_mon is 0-based (0 = January)
  t.tm_mday = dateTime.date.date;
  t.tm_hour = dateTime.time.hours;
  t.tm_min = dateTime.time.minutes;
  t.tm_sec = dateTime.time.seconds;
  t.tm_isdst = -1; // Daylight saving time (let the system determine)

  // Convert to time_t
  Serial.println("time synched from RTC");
  return mktime(&t);
}

time_t getNtpTime()
{
  IPAddress ntpServerIP;

  while (Udp.parsePacket() > 0)
    ; // discard any previously received packets
  Serial.println("Transmit NTP Request");
  // get a random server from the pool
  WiFi.hostByName(ntpServerName, ntpServerIP);
  Serial.print(ntpServerName);
  Serial.print(": ");
  Serial.println(ntpServerIP);
  sendNTPpacket(ntpServerIP);
  uint32_t beginWait = millis();
  while (millis() - beginWait < 1500)
  {
    int size = Udp.parsePacket();
    if (size >= NTP_PACKET_SIZE)
    {
      Serial.println("Receive NTP Response");
      Udp.read(packetBuffer, NTP_PACKET_SIZE); // read packet into the buffer
      unsigned long secsSince1900;
      // convert four bytes starting at location 40 to a long integer
      secsSince1900 = (unsigned long)packetBuffer[40] << 24;
      secsSince1900 |= (unsigned long)packetBuffer[41] << 16;
      secsSince1900 |= (unsigned long)packetBuffer[42] << 8;
      secsSince1900 |= (unsigned long)packetBuffer[43];
      unsigned long timeValue = secsSince1900 - 2208988800UL + timeZone * SECS_PER_HOUR;
      Serial.println("time synched from NTP server");
      return timeValue;
    }
  }
  Serial.println("No NTP Response :-(");
  return 0; // return 0 if unable to get the time
}

String getDownloadFilesJson()
{

  JsonDocument jsonDocument;

  File logDirectory = SD.open("/logs");

  if (!logDirectory)
  {
    return String();
  }
  if (!logDirectory.isDirectory())
  {
    return String();
  }

  File file = logDirectory.openNextFile();

  while (file)
  {
    if (!file.isDirectory())
    {
      int bytes = file.size();
      String fsize = "";
      if (bytes < 1024)
        fsize = String(bytes) + " B";
      else if (bytes < (1024 * 1024))
        fsize = String(bytes / 1024.0, 3) + " KB";
      else if (bytes < (1024 * 1024 * 1024))
        fsize = String(bytes / 1024.0 / 1024.0, 3) + " MB";
      else
        fsize = String(bytes / 1024.0 / 1024.0 / 1024.0, 3) + " GB";

      JsonObject arrayDocument = jsonDocument.add<JsonObject>();
      arrayDocument["Date"] = String(file.name()).substring(0, 10);
      arrayDocument["Filename"] = String(file.name());
      arrayDocument["Filesize"] = fsize;
      arrayDocument["DownloadUrl"] = "/downloads?filename=" + String(file.name());
    }
    file.close();
    file = logDirectory.openNextFile();
  }

  file.close();
  String jsonString;
  jsonDocument.shrinkToFit();
  serializeJson(jsonDocument, jsonString);

  return jsonString;
}

void updateVolume()
{
  M5.Speaker.setVolume((int)(settings.Volume / 100.00f * 255.0f));
}

String getSettingsJson()
{
  JsonDocument jsonDocument;

  jsonDocument["Volume"] = settings.Volume;
  jsonDocument["LowerWindspeedThreshold"] = settings.LowerWindspeedThreshold;
  jsonDocument["UpperWindspeedThreshold"] = settings.UpperWindspeedThreshold;
  jsonDocument["WindspeedDurationRange"] = settings.WindspeedDurationRange;
  jsonDocument["WindspeedEvaluationRange"] = settings.WindspeedEvaluationRange;
  jsonDocument["WindspeedNumberOfWindows"] = settings.WindspeedNumberOfWindows;
  jsonDocument["CalibrationFactor"] = settings.CalibrationFactor;
  jsonDocument["DisplayBrightness"] = settings.DisplayBrightness;
  jsonDocument["MaximumChargeCurrent"] = settings.MaximumChargeCurrent;

  String jsonString;
  jsonDocument.shrinkToFit();
  serializeJson(jsonDocument, jsonString);
  return jsonString;
}

String getTimestampString()
{
  time_t t = now();
  char stringbuffer[100];
  sprintf(stringbuffer, "%4u-%02u-%02u %02u:%02u:%02u", year(t), month(t), day(t), hour(t), minute(t), second(t));
  return String(stringbuffer);
}

String getStatusJson()
{

  JsonDocument jsonDocument;

  jsonDocument["BatteryLevel"] = M5.Power.getBatteryLevel();
  jsonDocument["Current"] = M5.Power.getBatteryCurrent();
  jsonDocument["IsPowerConnected"] = M5.Power.Axp192.isACIN();
  jsonDocument["IsCharging"] = M5.Power.isCharging();
  jsonDocument["WifiIpAddress"] = isAPModeActive ? WiFi.softAPIP() : WiFi.localIP();
  jsonDocument["WifiRSSI"] = WiFi.RSSI();
  jsonDocument["WifiMode"] = isAPModeActive ? "Accesspoint" : "WiFi";
  jsonDocument["WifiSSID"] = isAPModeActive ? AP_SSID : "NONE";
  jsonDocument["WifiHostname"] = String("http://") + MDNSNAME + String(".local");
  jsonDocument["DateTime"] = getTimestampString();
  jsonDocument["FirmwareVersion"] = String(FWVERSION);

  String jsonString;
  jsonDocument.shrinkToFit();
  serializeJson(jsonDocument, jsonString);
  return jsonString;
}

void updateSettings()
{
  windSpeed.updateSettings(settings.LowerWindspeedThreshold, settings.UpperWindspeedThreshold, settings.WindspeedDurationRange, settings.WindspeedEvaluationRange, settings.WindspeedNumberOfWindows, settings.CalibrationFactor);
  windSpeedDisplay.updateSettings(settings.LowerWindspeedThreshold, settings.UpperWindspeedThreshold, settings.WindspeedEvaluationRange, settings.WindspeedDurationRange, settings.DisplayBrightness);
  updateVolume();
  M5.Power.Axp192.setChargeCurrent(settings.MaximumChargeCurrent);
  saveSettings();
}

void handleDownloadRequest(AsyncWebServerRequest *request)
{

  Serial.print("Method: ");
  Serial.println(request->method());

  int headers = request->headers();
  int i;
  for (i = 0; i < headers; i++)
  {
    const AsyncWebHeader *h = request->getHeader(i);
    Serial.printf("_HEADER[%s]: %s\n", h->name().c_str(), h->value().c_str());
  }

  Serial.println("Params: ");
  for (size_t i = 0; i < request->params(); i++)
  {
    Serial.println(request->getParam(i)->name());
  }

  Serial.println("Args: ");
  for (size_t i = 0; i < request->args(); i++)
  {
    Serial.println(request->argName(i));
  }
  if (request->hasParam("filename", false))
  { // Check for files: <input name="filename" />

    String filename2 = request->arg("filename");
    Serial.println(filename2);
    Serial.println("getParam");
    const AsyncWebParameter *parameter = request->getParam(0);
    Serial.println(parameter->name());
    Serial.println(parameter->value());
    String filename = request->getParam("filename")->value();
    Serial.println("Download Filename: " + filename);
    request->send(SD, "/logs/" + filename, String(), true);
    return;
  }
  else
  {
    request->send_P(200, "application/json", getDownloadFilesJson().c_str());
  }
}

void playSound(uint32_t duration = 4294967295U, float frequency = 440.0f)
{
  M5.Speaker.tone(frequency, duration);
}

void playSwitchOffSound()
{
  if (!isSwitchoffSoundActive)
  {
    isSwitchoffSoundActive = true;
    int delayTime = 200;
    playSound(delayTime, 1320.0f);
    M5.delay(delayTime);
    playSound(delayTime, 880.0f);
    M5.delay(delayTime);
    playSound(delayTime, 440.0f);
    M5.delay(delayTime);
  }
}

void playSwitchOnSound()
{
  int delayTime = 200;
  playSound(delayTime, 440.0f);
  M5.delay(delayTime);
  playSound(delayTime, 880.0f);
  M5.delay(delayTime);
  playSound(delayTime, 1320.0f);
  M5.delay(delayTime);
}

void playAlarmSound() {
    playSound();
}

void stopSound()
{
  M5.Speaker.stop();
}

void setupSoundModule()
{
  updateVolume();
  M5.Speaker.begin();
}

void setupDns()
{
  if (!MDNS.begin(MDNSNAME))
  {
    Serial.println("Error setting up MDNS responder!");
  }
  else
  {
    Serial.println("mDNS responder started");
  }
}

void wifiManagerConfigModeCallback(WiFiManager *wifiManager)
{
  Serial.println("Entered wifi manager config mode");
  Serial.println(WiFi.softAPIP());
  Serial.println(wifiManager->getConfigPortalSSID());
  wifiConfigDisplay.setup();
  wifiConfigDisplay.draw(wifiManager->getConfigPortalSSID(), WiFi.softAPIP().toString());
}

void setupWifi()
{
  if (isAPModeActive)
  {
    const char *ssid = AP_SSID;
    WiFi.softAP(ssid);
    IPAddress IP = WiFi.softAPIP();
    Serial.print("AP IP address: ");
    Serial.println(IP);
  }
  else
  {
    WiFi.mode(WIFI_MODE_STA);
    wifiManager.setHostname(hostname);
    wifiManager.setAPCallback(wifiManagerConfigModeCallback);
    bool res;

    res = wifiManager.autoConnect(AP_SSID);

    if (!res)
    {
      Serial.println("Failed to connect");
    }
    else
    {
      Serial.println("Connected successfull");
    }

    Serial.print("IP number assigned by DHCP is ");
    Serial.println(WiFi.localIP());
  }
  setupDns();
}

void setupRtcTimeSyncProvider()
{
  setSyncProvider(getRtcTime);
  setSyncInterval(TIME_SYNC_INTERVAL);
}

void setupNtpTimeSyncProvider()
{
  Serial.println("Starting UDP");
  Udp.begin(localPort);
  Serial.println("waiting for sync");
  setSyncProvider(getNtpTime);
  setSyncInterval(TIME_SYNC_INTERVAL);
  Serial.println("NTP Sync done");
}

void setupRtc()
{

  if (!M5.Rtc.isEnabled())
  {
    Serial.println("RTC not found.");
    return;
  }

  Serial.println("RTC found.");
  auto dt = M5.Rtc.getDateTime();

  if (!isWifiOn || isAPModeActive)
  {
    setupRtcTimeSyncProvider();
  }
  else
  {
    setupNtpTimeSyncProvider();
  }

  // update RTC with current system time
  time_t t = now();
  M5.Rtc.setDateTime(gmtime(&t));
}

void evaluationCallback()
{
  isAlarmActive = true;
  playAlarmSound();
}

void startButtonCallback(bool isWifiEnabled, bool isAPEnabled)
{
  isAPModeActive = isAPEnabled;
  isWifiOn = isWifiEnabled;
  isStartupActive = false;
}

void setupWindspeedIO()
{
  windSpeed.setupInterruptCallback(interruptCallback);
  windSpeed.setupEvaluationCallback(&evaluationCallback);
}

// callback definition
void parseMyPageBody(AsyncWebServerRequest *req, uint8_t *data, size_t len, size_t index, size_t total)
{
  DynamicJsonDocument bodyJSON(1024);
  deserializeJson(bodyJSON, data, len);
  int volume = bodyJSON["Volume"];
  int lowerWindspeedThreshold = bodyJSON["LowerWindspeedThreshold"];
  int upperWindspeedThreshold = bodyJSON["UpperWindspeedThreshold"];
  settings.WindspeedDurationRange = bodyJSON["WindspeedDurationRange"];
  settings.WindspeedNumberOfWindows = bodyJSON["WindspeedNumberOfWindows"];
  // int calibrationValue = bodyJSON["CalibrationValue"];
  int displayBrightness = bodyJSON["DisplayBrightness"];
  int maximumChargeCurrent = bodyJSON["MaximumChargeCurrent"];
  settings.Volume = volume;
  settings.LowerWindspeedThreshold = lowerWindspeedThreshold;
  settings.UpperWindspeedThreshold = upperWindspeedThreshold;
  // settings.CalibrationFactor = calibrationValue;
  settings.DisplayBrightness = displayBrightness;
  settings.MaximumChargeCurrent = maximumChargeCurrent;
  updateSettings();
}

void handleSettings(AsyncWebServerRequest *request)
{
  Serial.println("handleSettings");
  request->send_P(200, "application/json", getSettingsJson().c_str());
}

void handleResetWifi(AsyncWebServerRequest *request)
{
  Serial.println("handleResetWifi");
  wifiManager.resetSettings();
  request->send(200, "text/plain", "Resetting WiFi settings");
}


void setupServer()
{

  server.on("/chart.js", HTTP_GET, [](AsyncWebServerRequest *request)
            { request->send(LittleFS, "/chart.js"); });
  server.on("/favicon.ico", HTTP_GET, [](AsyncWebServerRequest *request)
            { request->send(LittleFS, "/favicon.ico"); });
  server.on("/", HTTP_GET, [](AsyncWebServerRequest *request)
            { request->send(LittleFS, "/index.html"); });
  server.on("/windspeed", HTTP_GET, [](AsyncWebServerRequest *request)
            { request->send_P(200, "application/json", windSpeed.getWindspeedJson().c_str()); });
  server.on("/evaluation", HTTP_GET, [](AsyncWebServerRequest *request)
            { request->send_P(200, "application/json", windSpeed.getWindspeedEvaluationJson().c_str()); });
  server.on("/downloads", HTTP_GET, [](AsyncWebServerRequest *request)
            { handleDownloadRequest(request); });
  server.on("/settings", HTTP_GET, [](AsyncWebServerRequest *request)
            { request->send_P(200, "application/json", getSettingsJson().c_str()); });
  server.on("/status", HTTP_GET, [](AsyncWebServerRequest *request)
            { request->send_P(200, "application/json", getStatusJson().c_str()); });
  server.on("/settings", HTTP_POST, handleSettings, nullptr, parseMyPageBody);
  server.on("/resetwifi", HTTP_POST, handleResetWifi);

  DefaultHeaders::Instance().addHeader("Access-Control-Allow-Origin", "*");

  updateServer.setup(&server);

  updateServer.onUpdateBegin = [](const UpdateType type, int &result)
  {
    Serial.println("Update started : " + String(type));
  };
  updateServer.onUpdateEnd = [](const UpdateType type, int &result)
  {
    Serial.println("Update finished : " + String(type) + " result: " + String(result));
  };

  Serial.println("Server begin");
  server.begin();
}

void setupLittleFS()
{
  if (!LittleFS.begin())
  {
    Serial.println("An Error has occurred while mounting LittleFS");
    return;
  }
}
void saveSettings()
{
  preferences.begin(PREFERENCE_NAMESPACE, false);
  preferences.putInt("Volume", settings.Volume);
  preferences.putInt("LowerThreshold", settings.LowerWindspeedThreshold);
  preferences.putInt("UpperThreshold", settings.UpperWindspeedThreshold);
  preferences.putInt("DurationRange", settings.WindspeedDurationRange);
  preferences.putInt("EvaluationRange", settings.WindspeedEvaluationRange);
  preferences.putInt("NumberOfWindows", settings.WindspeedNumberOfWindows);
  preferences.putInt("Calibration", settings.CalibrationFactor);
  preferences.putInt("Brightness", settings.DisplayBrightness);
  preferences.putInt("MaxCurrent", settings.MaximumChargeCurrent);
  preferences.end();
  Serial.println("Preferences saved");
}

void setupPreferences()
{
  preferences.begin(PREFERENCE_NAMESPACE, false);
  settings.Volume = preferences.getInt("Volume", VOLUME);
  settings.LowerWindspeedThreshold = preferences.getInt("LowerThreshold", WINDSPEED_LOWER_THRESHOLD);
  settings.UpperWindspeedThreshold = preferences.getInt("UpperThreshold", WINDSPEED_UPPER_THRESHOLD);
  settings.WindspeedDurationRange = preferences.getInt("DurationRange", WINDSPEED_DURATION_RANGE);
  settings.WindspeedEvaluationRange = preferences.getInt("EvaluationRange", WINDSPEED_EVALUATION_RANGE);
  settings.WindspeedNumberOfWindows = preferences.getInt("NumberOfWindows", WINDSPEED_NUMBER_OF_WINDOWS);
  settings.CalibrationFactor = preferences.getInt("Calibration", 1);
  settings.DisplayBrightness = preferences.getInt("Brightness", DISPLAY_BRIGHTNESS);
  settings.MaximumChargeCurrent = preferences.getInt("MaxCurrent", CHARGE_CURRENT);
  preferences.end(); 
  saveSettings();
  updateSettings();
}

void setupStartupLogo()
{
  File pngLogo = LittleFS.open("/FxWindStartLogo.png", "r");
  Serial.println("Logo size: " + String(pngLogo.size()));
  display.begin();
  display.drawPng(&pngLogo, 1, 18);
  delay(3000);
  display.clear();
}

void setupStartupDisplay()
{
  playSwitchOnSound();
  startupDisplay.setup(255);
  startupDisplay.setupStartButtonCallback(&startButtonCallback);
  startupDisplay.draw();
  while (isStartupActive)
  {
    delay(1);
    startupDisplay.evaluateTouches();
  }
}

void setupM5()
{
  auto config = M5.config();
  config.external_speaker.atomic_spk = true;
  config.external_speaker.module_display = true;
  config.external_rtc = true;
  M5.begin();
}

void switchOffWifi()
{
  Serial.println("Stop Wifi");
  esp_err_t results = esp_wifi_stop();
}

void switchOnWifi()
{
  Serial.println("Start Wifi");
  esp_err_t results = esp_wifi_start();
  if (!isAPModeActive)
  {
    WiFi.reconnect();
  }
}

void setup(void)
{
  // order of initialization is important
  setupM5();
  windSpeed.setup();
  setupWindspeedIO();
  setupSoundModule();
  setupLittleFS();
  setupStartupDisplay();
  setupWifi();
  setupRtc();
  setupServer();
  windSpeedDisplay.setup();
  setupPreferences();
  if (!isWifiOn)
  {
    switchOffWifi();
  }
}

void startDeepSleep()
{
  esp_sleep_enable_ext0_wakeup(GPIO_NUM_39, 0); // gpio39 == touch INT
  delay(100);
  M5.Display.fillScreen(TFT_BLACK);
  M5.Display.sleep();
  M5.Display.waitDisplay();
  esp_deep_sleep_start();
}

void evaluateTouches()
{
  auto count = M5.Touch.getCount();
  if (count != 0)
  {
    static m5::touch_state_t prev_state;
    auto touchDetail = M5.Touch.getDetail();

    if (touchDetail.wasFlicked())
    {

      if (abs(touchDetail.distanceX()) > 30 && (abs(touchDetail.distanceX()) > abs(touchDetail.distanceY())))
      {
        if (touchDetail.distanceX() > 0)
        {
          if (menuX == 4)
          {
            menuX = 0;
          }
          else
          {
            menuX++;
          }
        }
        else
        {
          if (menuX == 0)
          {
            menuX = 4;
          }
          else
          {
            menuX--;
          }
        }
        windSpeedDisplay.draw((DrawType)menuX);
      }
    }

    if (touchDetail.wasPressed())
    {
      touchDuration = millis();
    }

    if (touchDetail.wasReleased())
    {
      int duration = millis() - touchDuration;
      touchDuration = 0;
      if (duration > 3000)
      {
        startDeepSleep();
      }
    }

    if (touchDetail.wasDragged())
    {
      startDeepSleep();
    }

    if (isAlarmActive && touchDetail.getClickCount() == 2)
    {
      stopSound();
      isAlarmActive = false;
    }
  }
}

void loop(void)
{
  M5.delay(1);
  M5.update();
  evaluateTouches();

  if (touchDuration > 0 && (millis() - touchDuration) > 3000)
  {
    playSwitchOffSound();
  }

  long currentMillis = millis();
  if (currentMillis - lastMillis >= SAMPLE_RATE)
  {
    windSpeed.calculateWindspeed(true, true);
    lastMillis = currentMillis;
    windSpeedDisplay.draw((DrawType)menuX);
  }
}

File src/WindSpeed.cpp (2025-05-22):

#include "WindSpeed.h"

WindSpeed::WindSpeed(uint8_t sensorPin, uint16_t windspeedLowerThreshold, uint16_t windspeedUpperThreshold, uint16_t windspeedDurationRange, uint16_t evaluationRange, uint16_t numberOfWindowsThreshold, uint16_t calibrationFactor)
{
    _sensorPin = sensorPin;
    pinMode(_sensorPin, INPUT_PULLUP);
    _evaluationRange = evaluationRange;
    _windspeedLowerThreshold = windspeedLowerThreshold;
    _windspeedUpperThreshold = windspeedUpperThreshold;
    _windspeedDurationRange = windspeedDurationRange;
    _numberOfWindowsThreshold = numberOfWindowsThreshold;
    _calibrationFactor = calibrationFactor;
}

void WindSpeed::setup()
{
    setupSDCard();
}

void WindSpeed::updateSettings(uint16_t windspeedLowerThreshold, uint16_t windspeedUpperThreshold, uint16_t windspeedDurationRange, uint16_t evaluationRange, uint16_t numberOfWindowsThreshold, uint16_t calibrationFactor)
{
    _windspeedLowerThreshold = windspeedLowerThreshold;
    _windspeedUpperThreshold = windspeedUpperThreshold;
    _windspeedDurationRange = windspeedDurationRange;
    _evaluationRange = evaluationRange;
    _numberOfWindowsThreshold = numberOfWindowsThreshold;
    _calibrationFactor = calibrationFactor;
}

void WindSpeed::setupSDCard()
{
    if (!SD.begin(GPIO_NUM_4, SPI, 25000000))
    {
        Serial.println("Card Mount Failed");
        return;
    }
    uint8_t cardType = SD.cardType();

    if (cardType == CARD_NONE)
    {
        Serial.println("No SD card attached");
        return;
    }

    Serial.print("SD Card Type: ");
    if (cardType == CARD_MMC)
    {
        Serial.println("MMC");
    }
    else if (cardType == CARD_SD)
    {
        Serial.println("SDSC");
    }
    else if (cardType == CARD_SDHC)
    {
        Serial.println("SDHC");
    }
    else
    {
        Serial.println("UNKNOWN");
    }
    Serial.printf("SD Card Size: %lluMB\n", SD.cardSize() / (1024 * 1024));
    Serial.printf("Total space: %lluMB\n", SD.totalBytes() / (1024 * 1024));
    Serial.printf("Used space: %lluMB\n", SD.usedBytes() / (1024 * 1024));

    createDir(SD, "/logs");
}

void WindSpeed::setupInterruptCallback(void (*externalInterruptCallback)(void))
{
    attachInterrupt(digitalPinToInterrupt(_sensorPin), externalInterruptCallback, RISING);
}

void WindSpeed::setupEvaluationCallback(std::function<void(void)> evaluationCallback)
{
    _evaluationCallback = evaluationCallback;
}

// interrupt callback function for impuls counter of windspeed sensor
void WindSpeed::interruptCallback()
{
    _counter++;
}

// windspeed in m/s
void WindSpeed::calculateWindspeed(bool evaluate, bool log)
{
    float windspeed = ((float)(_counter - _lastCounter) / 20.0f * 1.75f * 1000 / _sampleRate);
    _lastCounter = _counter;
    updateWindspeedArray(windspeed);
    if (evaluate)
    {
        evaluateWindspeed();
    }
    if (log)
    {
        logWindspeedToSDCard(SD);
    }
}

float WindSpeed::getCurrentWindspeed()
{
    float currentWindspeed = ((float)_windspeedHistoryArray[0] / 10.0f);
    return currentWindspeed;
}

WindspeedEvaluation WindSpeed::getWindspeedEvaluation()
{
    return _windspeedEvaluation;
}

int WindSpeed::getWindSpeedHistoryArrayElement(int i)
{
    return _windspeedHistoryArray[i];
}

void WindSpeed::evaluateWindspeed()
{

    int maxWindspeed = 0;
    int minWindspeed = INT_MAX;
    long sumWindspeed = 0;

    int rangeCounter = 0;
    int exceededRangesCounter = 0;
    int numberOfRanges = _evaluationRange / _windspeedDurationRange;
    int exceededRangesIndex[numberOfRanges];

    for (size_t i = 0; i < 30; i++)
    {
        _windspeedEvaluation.RangeStartIndex[i] = 0;
        _windspeedEvaluation.RangeStopIndex[i] = 0;
    }

    for (size_t i = 0; i < numberOfRanges; i++)
    {
        exceededRangesIndex[i] = 0;
    }

    for (size_t i = _evaluationRange; i > 0; --i)
    {
        if (_windspeedHistoryArray[i] > maxWindspeed)
        {
            maxWindspeed = _windspeedHistoryArray[i];
        }

        if (_windspeedHistoryArray[i] < minWindspeed)
        {
            minWindspeed = _windspeedHistoryArray[i];
        }
        sumWindspeed += _windspeedHistoryArray[i];

        if (_windspeedHistoryArray[i] < _windspeedLowerThreshold * 10 
            || _windspeedHistoryArray[i] > _windspeedUpperThreshold * 10)
        {
            rangeCounter++;
        }

        if (rangeCounter == _windspeedDurationRange)
        {
            exceededRangesIndex[exceededRangesCounter] = i;
            exceededRangesCounter++;
            rangeCounter = 0;
        }

        if (_windspeedHistoryArray[i] >= _windspeedLowerThreshold * 10 
            && _windspeedHistoryArray [i] <= _windspeedUpperThreshold * 10)
        {
            rangeCounter = 0;
        }
    }

    _windspeedEvaluation.NumberOfExceededRanges = exceededRangesCounter;
    _windspeedEvaluation.MaxWindspeed = (float)maxWindspeed / 10.0f;
    _windspeedEvaluation.MinWindspeed = (float)minWindspeed / 10.0f;
    _windspeedEvaluation.AverageWindspeed = (float)(sumWindspeed / _evaluationRange) / 10.0f;
    for (size_t i = 0; i < numberOfRanges; i++)
    {
        _windspeedEvaluation.RangeStartIndex[i] = exceededRangesIndex[i];
        _windspeedEvaluation.RangeStopIndex[i] = exceededRangesIndex[i] + _windspeedDurationRange;
    }

    if (exceededRangesCounter < _numberOfWindowsThreshold)
    {
        _isCallbackAlreadySent = false;
    }

    if (exceededRangesCounter >= _numberOfWindowsThreshold && !_isCallbackAlreadySent && _evaluationCallback != nullptr)
    {
        _isCallbackAlreadySent = true;
        _evaluationCallback();
        storeSnapshot();
    }
}

String WindSpeed::getWindspeedString(bool addUnitSymbol)
{
    char stringbuffer[100];
    if (addUnitSymbol)
    {
        sprintf(stringbuffer, "%.1f m/s  ", getCurrentWindspeed());
    }
    else
    {
        sprintf(stringbuffer, "%.1f", getCurrentWindspeed());
    }
    return String(stringbuffer);
}

String WindSpeed::getWindspeedEvaluationSingleString(float windspeedValue)
{
    char stringbuffer[100];
    sprintf(stringbuffer, "%.1f", windspeedValue);
    return String(stringbuffer);
}

void WindSpeed::logWindspeedToSDCard(fs::FS &fs)
{
    if (!fs.exists(getLogFilePath().c_str()))
    {
        writeLineToFile(fs, getLogFilePath().c_str(), getLogFileHeader().c_str());
    }
    appendLineToFile(fs, getLogFilePath().c_str(), getLogCsvRow().c_str());
}

String WindSpeed::getWindspeedEvaluationString()
{
    return "MAX:" + getWindspeedEvaluationSingleString(_windspeedEvaluation.MaxWindspeed) + " MIN:" + getWindspeedEvaluationSingleString(_windspeedEvaluation.MinWindspeed) + " AVG:" + getWindspeedEvaluationSingleString(_windspeedEvaluation.AverageWindspeed);
}

String WindSpeed::getTimestampString()
{
    time_t t = now();
    return getTimestampString(t);
}
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

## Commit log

2024-09-24 fine tune evaluation bars and correct index calculation
    [main.cpp]
2025-03-24 add initial event callback with sound and touch reset
    [WindSpeed.cpp, WindSpeed.h, main.cpp]
2025-03-25 add status and configuration screens
    [ConfigurationDisplay.h]
2025-03-25 reduce to the max (remove config and status screen again)
    should be done only via web view
    [ConfigurationDisplay.h]
2025-03-26 change input pin for M5 Tough
2025-03-28 bugfix sd csv log (unit added, when windpseed above 0)
    [WindSpeed.cpp, WindSpeed.h]
2025-04-03 add battery level and voltage to sd log
2025-04-10 add first draft of assembly instruction
2025-04-17 add initial battery display screen
2025-04-28 updated assembly documentation
2025-04-28 Revert "updated assembly documentation"
    This reverts commit df00cf07cd6e8a916d1dacc531d733bd6c4b9b7f.
2025-04-30 add 3D files
    [FxWind.3mf, FxWind.f3d, FxWind_Case.stl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]
2025-05-01 no task
    [BottomStand.stl, TopStand.stl]
